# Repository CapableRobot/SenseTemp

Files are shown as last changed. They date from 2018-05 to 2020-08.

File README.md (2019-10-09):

# SenseTemp

Designed by [Capable Robot Components](http://capablerobot.com).  
Follow us on [Twitter](http://twitter.com/capablerobot) for product announcements and updates.

---

**SenseTemp is available on [CrowdSupply](https://www.crowdsupply.com/capable-robot-components/sensetemp) & [Mouser](https://www.mouser.com/Search/Refine?Keyword=sensetemp).  Please visit the [campaign page](https://www.crowdsupply.com/capable-robot-components/sensetemp) or [Mouser](https://www.mouser.com/ProductDetail/Crowd-Supply/cs-sensetemp-01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) for product information and to purchase SenseTemp.** 

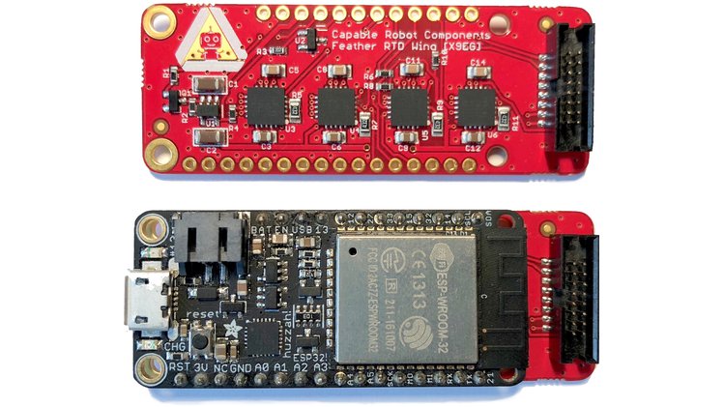
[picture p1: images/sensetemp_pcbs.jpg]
SenseTemp PCB Image


SenseTemp provides four highly accurate and flexible temperature sensors which allow you to understand the operation of your:

* Mobile robot
* Embedded system 
* Double pane windows on your house
* Home brewing operation
* Or any other system where temperature and thermal conduction is important

It's designed for quick tests as well as long-duration process monitoring.

## SenseTemp Features 

* **Small:** so that it can be on a mobile system being tested.  The RTDs themselves are 2 mm x 4 mm, making them thermally responsive and great for measurement of point heat sources
* **Inexpensive:** allowing many points of temperature monitoring
* **Battery Powered:** including LiPoly & USB power banks
* **Wireless:** to make test setup faster and more flexible
* **Open Software:** so that the device can directly feed data into a data logging system of your choice
* **Open Hardware:** to enable derivative designs and for easy hacking

## Specifications

|Feature|Specification|
|----|----|
|Sensors|4x Platinum resistance temperature detectors (RTDs)|
|RTD Accuracy|±0.15°C|
|Temperature Range|-50°C to 260°C|
|Interface ICs|4x [MAX31865](https://www.maximintegrated.com/en/products/sensors/MAX31865.html) with 4 wire sensing|
|Form Factor|[Adafruit Feather](https://www.adafruit.com/feather)|
|Dimensions|0.9" x 2.4"|

## Feather Hosts

SenseTemp is designed to mate with Adafruit Feather-compatible host modules, like:

* [Adafruit Feather M4 Express](https://www.adafruit.com/product/3857)
* [Adafruit Feather M0 Express](https://www.adafruit.com/product/3403)
* [Adafruit ESP32 Feather Host](https://www.adafruit.com/product/3405)
* [Adafruit HalloWing](https://www.adafruit.com/product/3900)

Note that the ES8266 Feather is **NOT** supported due to the limited IO on the ESP8266.  It does not have enough pins to support the four SPI devices of the SenseTemp.

## Software

The software running on the Feather host processor does change based on the feather host you are using.  This repository contains software for:

* [**CircuitPython:**](software-circuitpython) if you are using a Cortex M4 or M0 Feather.  
* [**MicroPython:**](software-micropython) if you are using an ESP32 Feather.  The ESP32 is not currently supported by CircuitPython.

## Hardware Revisions

* [CREAES](revisions/CREAES) : Last release 2018-10-18.
	* Changed from 0805 to 0603 passive components.
	* Moved all components to top side of PCB.
	* Changed license from **CC BY-SA 4.0** to **CERN OHL v1.2**.
	* Can be powered from either USB or Li-Ion sources.
* [X9EG](revisions/X9EG) : Released 2018-08-28.
	* Added `SIO` pin with AT21CS01 1-Wire EEPROM for configuration & serialization.
	* Added `EN` pin to allow host PCB to disable 5v to 3v regulator on this PCB.
	* Changed RTD connector from 20 pin (used on XTMT version) to 16 pin.
* [XTMT](revisions/XTMT) : Initial version released 2018-05-18.

## License Information

| **Type** | **License** |
| --- | --- |
| Hardware | Copyright Capable Robot Components 2018 <br><br>This documentation describes Open Hardware and is licensed under the [CERN OHL v1.2 or later](https://www.ohwr.org/licenses/cern-ohl/license_versions/v1.2). <br/><br/> You may redistribute and modify this documentation under the terms of the CERN OHL v.1.2.  This documentation is distributed WITHOUT ANY EXPRESS OR IMPLIED WARRANTY, INCLUDING OF MERCHANTABILITY, SATISFACTORY QUALITY AND FITNESS FOR A PARTICULAR PURPOSE. Please see the CERN OHL v.1.2 for applicable conditions |
| Software | [MIT License](LICENSE.txt) |
| Documentation | [Creative Commons Attribution-ShareAlike](https://creativecommons.org/licenses/by-sa/4.0/) License |

More detailed information about the CERN License is available in the [license](license) folder and on the [CERN website](https://www.ohwr.org/projects/cernohl/wiki).

| **OSHW Certification** |
| --- |
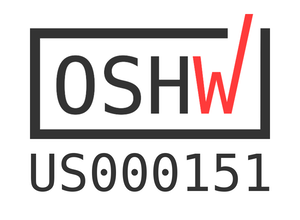
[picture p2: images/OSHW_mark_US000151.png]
OSHW Mark US000151
|  | 
| [Certified open source hardware](https://certification.oshwa.org/us000151.html) by the [Open Source Hardware Association](https://www.oshwa.org) |

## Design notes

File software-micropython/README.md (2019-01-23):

# MicroPython SenseTemp

Designed by [Capable Robot Components](http://capablerobot.com).  Follow us on [Twitter](http://twitter.com/capablerobot) for product announcements and updates.

---

This folder contains MicroPython software for use of the SenseTemp with the [Adafruit ESP32 Feather Host](https://www.adafruit.com/product/3405).

## System Setup

1. Install tools

```
pip3 install esptool adafruit-ampy
```

2. Flash MicroPython onto the device

```
espefuse.py --port /dev/ttyUSB1 set_flash_voltage 3.3V
esptool.py --port /dev/ttyUSB1 --chip esp32 erase_flash
esptool.py --port /dev/ttyUSB1 --chip esp32  write_flash -z 0x1000 ../firmware/esp32-20180511-v1.9.4.bin
```

The first command is necessary if the SenseTemp PCB has been soldered to the ESP32 module, due to the PCB pulling up GPIO12 (the SIO pin).

On MacOS, the port name will likely be `/dev/tty.SLAB_USBtoUART`.

By default, the ESP32 sees that as a signal to provide the flash chip with 1.8v instead of the default 3.3v.  This causes the SPI flash to brown out during writing and the MD5 checksum verify step will fail (because the flash is corrupted).  Setting the EFUSE causes the ESP32 to ignore the GPIO12 pin and always provide 3.3v to the SPI flash.

3. Load MicroPython source files (see below)

### Console Demo

```
ampy put lib
ampy put main-console.py main.py
```

### MQTT Demo

After creating the JSON file, you'll need to edit it to have your correct WIFI and Adafruit.io information.

```
cp settings-mqtt.json.example settings-mqtt.json 
ampy put lib
ampy put settings-mqtt.json 
ampy put main-mqtt.py main.py
```

### WIFI Demo

After creating the JSON file, you'll need to edit it to have your correct WIFI information.  Due the size of the `www` folder, this will take a few minutes.  Be patient.  

```
cp settings.json.example settings.json 
ampy put lib
ampy put www
ampy put settings.json
ampy put main.py
```

## Development

During development, it's best to load the main file under a different name so that the firmware does not automatically execute it.  

If the MicroPython code hangs, the ampy tool has a hard time putting the ESP32 module into raw communication mode (wherein it can upload files).  These commands can be used to 

1. Upload the in-development main.py file
2. Open a serial console (you will need to change the path) to the MicroPython REPL.
3. Start the in-development software.  Errors will be printed to the REPL.

```
ampy put main.py tmp.py
screen /dev/ttyUSB1 115200
> from tmp import *
```

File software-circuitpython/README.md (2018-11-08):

# SenseTemp with CircuitPython

Designed by [Capable Robot Components](http://capablerobot.com).  
Follow us on [Twitter](http://twitter.com/capablerobot) for product announcements and updates.

---

**SenseTemp is currently in-pre launch on CrowdSupply.  You can sign up on the [campaign page](https://www.crowdsupply.com/capable-robot-components/sensetemp) for project update.** 

---

During the [2018 Hackaday Supercon](https://hackaday.io/superconference/), Adafruit donated HalloWing badges to the attendees and I wrote the CiruitPython code released here, which graphs temperatures from SenseTemp on the HalloWing LCD.  

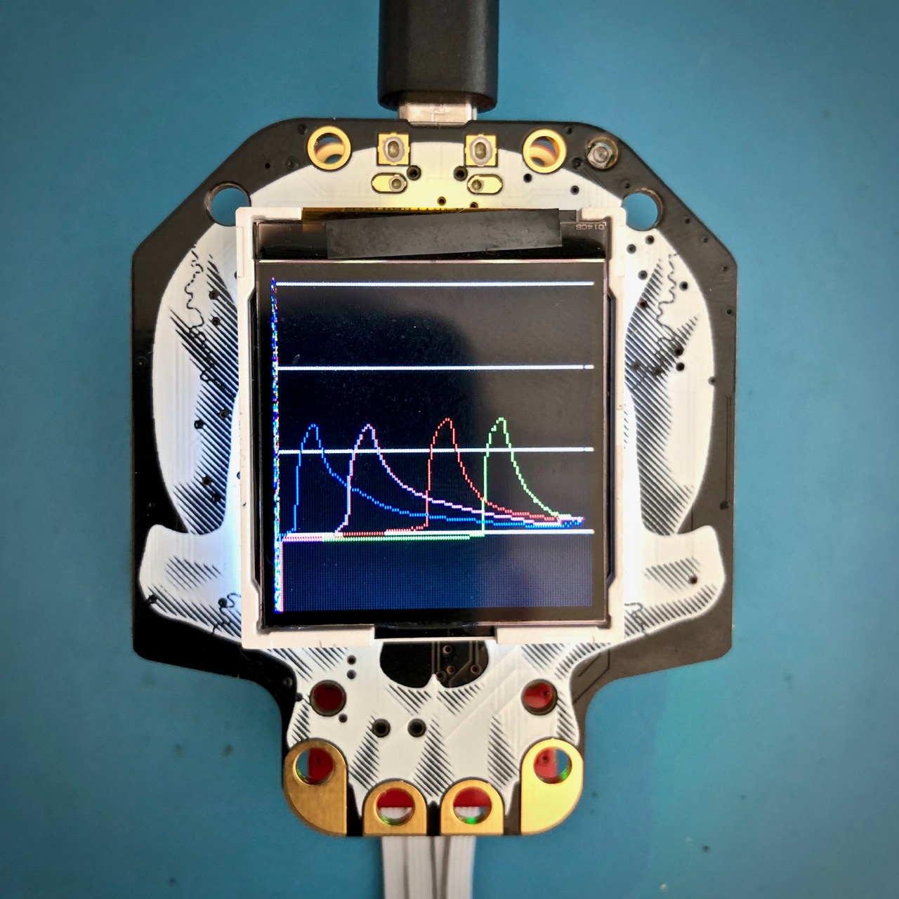
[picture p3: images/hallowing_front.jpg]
Hallowing displaying temperature data from SenseTemp
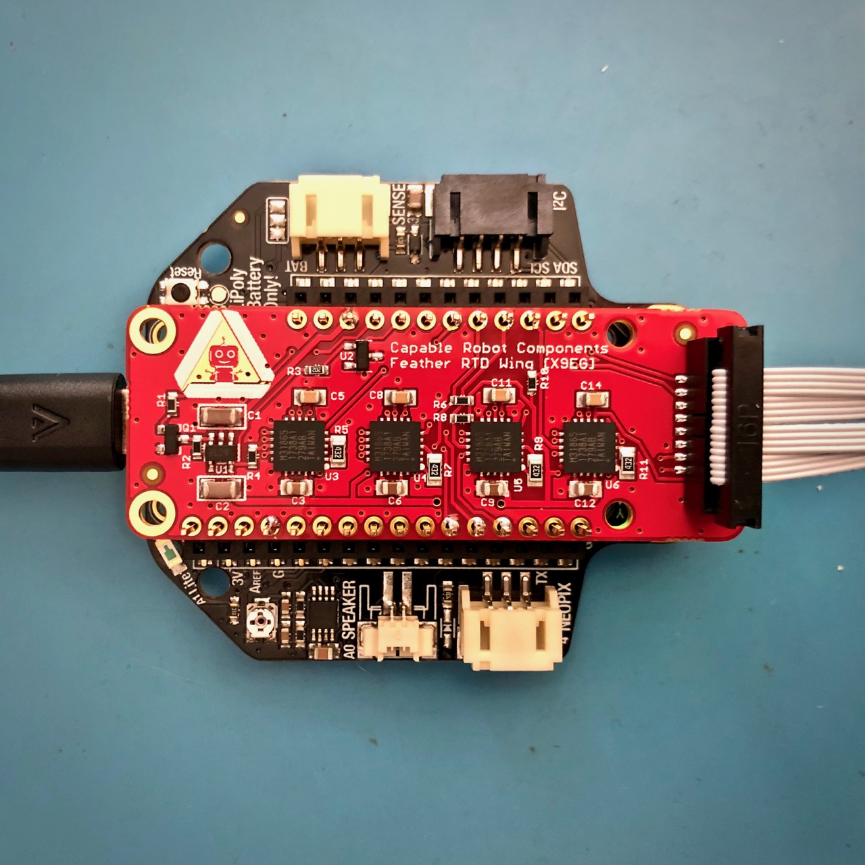
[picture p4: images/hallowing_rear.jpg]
SenseTemp installed into HalloWing Feather socket
|||
|:---:|:---:|
|HalloWing showing a time-history graph of the four temperature sensors.  Vertical scale is 60F to 100F.| Rear of HallowWing, showing SenseTemp board installed|

The full code is in `code-hallowing.py`, which should be renamed `code.py` so that it is auto-run by CircuitPython.

The main part of the display routine is shown here:

```python
## Determine vertical position for the temperature sample
def f_to_px(value):
    if value < TEMP_MIN:
        return 0

    if value > TEMP_MAX:
        return DISPLAY_PX-1

    px = (value - TEMP_MIN) * DISPLAY_PX / (TEMP_MAX - TEMP_MIN)
    return int(px)

## Re-draw the grid data at this position
def draw_grid_at_position(position):
    ## Clear all samples at this X position.
    display.vline(position, 0, DISPLAY_PX, color565(0,0,0))

    ## Draw white grid lines at this X position
    ## to re-create the temperature scale
    for value in temp_grid:
        y = f_to_px(value)
        display.pixel(position, y, color565(255,255,255))

## Stores the last PX position for each temperature value
## this allows code to determine if new sample should be
## drawing with a point, or a line
last_px = [0,0,0,0]

def draw_temps_graph(position, data):
    draw_grid_at_position(position)

    for idx,value in enumerate(data):
        y     = f_to_px(c_to_f(value))
        dy    = abs(y - last_px[idx])
        color = color565(*COLORMAP[idx])

        if dy > 1:
            ypos = min(y, last_px[idx])
            display.vline(position, ypos, dy, color)
        else:
            display.pixel(position, y, color)

        last_px[idx] = y

## Draw horizontal lines as a temperature scale
for value in temp_grid:
    y = f_to_px(value)
    display.hline(0, y, DISPLAY_PX, color565(255,255,255))

## Start on the left side of the screen
position = DISPLAY_PX

## Advance to the next PX position, read temperature data, draw it
while True:
    position -= 1

    data = [sensor.temperature for sensor in sensors]
    draw_temps_graph(position, data)

    ## We're at the end of the display, go back to the left side
    if position <= 0:
        position = DISPLAY_PX
```

Nearly any Feather Host running CircuitPython will support SenseTemp.  The only exception known to date is the ESP8266 Host as it does not have enough IO pins for the 4 SPI chip select pins.

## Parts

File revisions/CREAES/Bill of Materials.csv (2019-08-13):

Name | Mpn | Count | Device | Value | Package | Mfg | Cost | Description
C15,C16 | CL21A106KPFNNNE | 2 | CAP-0805 | 10u | 0805 | Samsung | 0.1088
C3,C4,C6,C7,C9,C10,C12,C13 | MF-CAP-0603-0.1uF | 8 | CAP-0603 | 100n | 0603 | Generic
C5,C8,C11,C14 | MF-CAP-0603-0.01uF | 4 | CAP-0603 | 10n | 0603 | Generic
D1 | MBR120VLSFT3G | 1 | DIODE-SCHOTTKY-SOD-123 | MBR120 | SOD-123 | ON Semiconductor | 0.16
FB1,FB2,FB3,FB4 | BK1608HW601-T | 4 | FER-0603 | 600R | 0603 | Taiyo Yuden | 0.11350000000000002
Q1 | MMBT2222LT1G | 1 | TRANSISTOR_NPN-SOT23-3 | MMBT2222 | SOT23-3 | ON Semiconductor | 0.0642
Q2 | DMP2045U-7 | 1 | MOSFET-P | DMP2045 | SOT23-R | Diodes Inc. | 0.124
R1,R2,R3 | MF-RES-0603-1K | 3 | RES-0603 | 1k | 0603 | Generic
R12 | MF-RES-0603-100K | 1 | RES-0603 | 100k | 0603 | Generic
R4,R6,R8,R10,R16 | MF-RES-0603-10K | 5 | RES-0603 | 10k | 0603 | Generic
R5,R7,R9,R11 | ERA3ARW432V | 4 | RES-0603 | 4k3 0.05% | 0603 | Panasonic | 1.7916
RTD1 | 3221-16-0300-00 | 1 | CONN-16-ZT |  | CONN-2X8-050-SMT-ZT | CNC Tech | 0.946
U2 | AT21CS01-STUM10-T | 1 | AT21CS01 |  | SOT23 | Microchip | 0.1836
U3,U4,U5,U6 | MAX31865ATP+ | 4 | MAX31865 |  | QFN65P500X500X100-21T325 | Maxim Integrated | 12.336
U7 | AP2112K-3.3TRG1 | 1 | MIC5225 | 3v3 | SOT25 | Diodes Inc. | 0.15

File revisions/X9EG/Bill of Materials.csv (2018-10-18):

Name | Count | Device | Value | Package | Description
C1,C2 | 2 | CAP_CERAMIC-_1206 | 10uF | _1206
C3,C4,C6,C7,C9,C10,C12,C13 | 8 | CAP_CERAMIC-0805-NOOUTLINE | 0.1uF | 0805-NO
C5,C8,C11,C14 | 4 | CAP_CERAMIC-0805-NOOUTLINE | 10nF | 0805-NO
FB1,FB2,FB3,FB4 | 4 | FERRITE--0805NO |  | 0805-NO
J1 | 1 | CONN_12-NO_SILK |  | 1X12_NO_SILK
J2 | 1 | CONN_16-1X16_NO_SILK |  | 1X16_NO_SILK
Q1 | 1 | TRANS_NPN--MMBT2222AL | 600mA/40V | SOT23-3
R1 | 1 | RES-0603 | 1k | 0603
R2,R4,R6,R8,R10 | 5 | RES-0603 | 10k | 0603
R3 | 1 | RES-0603 | 2k | 0603
R5,R7,R9,R11 | 4 | RESISTOR-0805_NOOUTLINE | 4300Ω 0.1% | 0805-NO
RTD1 | 1 | CONN-16-ZT |  | CONN-2X8-050-SMT-ZT
U1 | 1 | VREG_SOT23-5 | MIC5225-3.3 | SOT23-5
U2 | 1 | AT21CS01 |  | SOT23
U3,U4,U5,U6 | 4 | TEMP_MAX31865 | MAX31865 | QFN20_4MM_0.65MM

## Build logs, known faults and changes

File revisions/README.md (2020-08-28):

# SenseTemp Hardware Revisions

Designed by [Capable Robot Components](http://capablerobot.com).  
Follow us on [Twitter](http://twitter.com/capablerobot) for product announcements and updates.

---

**SenseTemp is available on [CrowdSupply](https://www.crowdsupply.com/capable-robot-components/sensetemp) & [Mouser](https://www.mouser.com/Search/Refine?Keyword=sensetemp).  Please visit the [campaign page](https://www.crowdsupply.com/capable-robot-components/sensetemp) or [Mouser](https://www.mouser.com/ProductDetail/Crowd-Supply/cs-sensetemp-01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) for product information and to purchase SenseTemp.** 

SenseTemp PCB Image

---

* [CREAES](revisions/CREAES) : Last release 2018-10-18.
	* Changed from 0805 to 0603 passive components.
	* Moved all components to top side of PCB.
	* Changed license from **CC BY-SA 4.0** to **CERN OHL v1.2**.
	* Can be powered from either USB or Li-Ion sources.
* [X9EG](revisions/X9EG) : Released 2018-08-28.
	* Added `SIO` pin with AT21CS01 1-Wire EEPROM for configuration & serialization.
	* Added `EN` pin to allow host PCB to disable 5v to 3v regulator on this PCB.
	* Changed RTD connector from 20 pin (used on XTMT version) to 16 pin.
* [XTMT](revisions/XTMT) : Initial version released 2018-05-18.

---

Also in this folder are two adapter PCBs which allows SenseTemp's 50mil (4x 4-wire) connector to be adapted to 4x 2-way 5mm screw terminals, allowing SenseTemp to use 2-wire and 3-wire (in 2-wire mode) P1000 RTDs.

The 'stacking' design has the same outline and mounting as SenseTemp and is designed to stack vertically above SenseTemp using a [AMP Minitek 20021321-00016C4LF](https://octopart.com/20021321-00016c4lf-amphenol+icc+%2F+fci-12642443?r=sp) (or similar) connector.

The 'cabled' design is smaller and cabled to SenseTemp via a 16 conductor, 50 mil ribbon cabled.  The recommended 16 pin connector for it is [CNC Tech 3221-16-0300-00](https://octopart.com/3221-16-0300-00-cnc+tech-47114357?r=sp) or similar.

Bare PCBs (e.g. no components installed or included) are available for purchase directly from OSHPark:

| [Cabled Adapter](https://oshpark.com/shared_projects/WjlpBAlQ) | [Stacking Adapter](https://oshpark.com/shared_projects/11pGTiwa) |
|---|---|
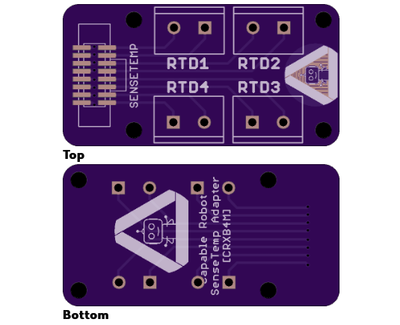
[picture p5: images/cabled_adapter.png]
Cabled Adapter Image (https://oshpark.com/shared_projects/WjlpBAlQ)
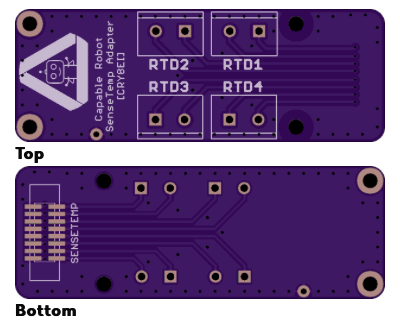
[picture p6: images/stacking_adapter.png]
Stacking Adapter Image (https://oshpark.com/shared_projects/11pGTiwa)
||  |

---

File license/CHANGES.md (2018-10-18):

Here we are compiling a community changelog.

If you come up with a modification of our designs, please share it
with the community, log your changes below, and upload the files to
our GitHub repository.

# Change Format

**NAME** on DATE by *Your name*.
Description of modification

# Change Log

* **[CREAES](https://github.com/CapableRobot/SenseTemp/tree/master/revisions/CREAES)** on 2018-10-18 by *Chris Osterwood*
	* Changed from 0805 to 0603 passive components.
	* Moved all components to top side of PCB.
	* Added `USR` pin for user-controllable LED near the RTD connector.
	* Changed license from **CC BY-SA 4.0** to **CERN OHL v1.2**.
* **[X9EG](https://github.com/CapableRobot/SenseTemp/tree/master/revisions/X9EG)** on 2018-08-28 by *Chris Osterwood*
	* Added `SIO` pin with AT21CS01 1-Wire EEPROM for configuration & serialization.
	* Added `EN` pin to allow host PCB to disable 5v to 3v regulator on this PCB.
	* Changed RTD connector from 20 pin (used on XTMT version) to 16 pin.
* **[XTMT](https://github.com/CapableRobot/SenseTemp/tree/master/revisions/XTMT)** 2018-05-18 by *Chris Osterwood*

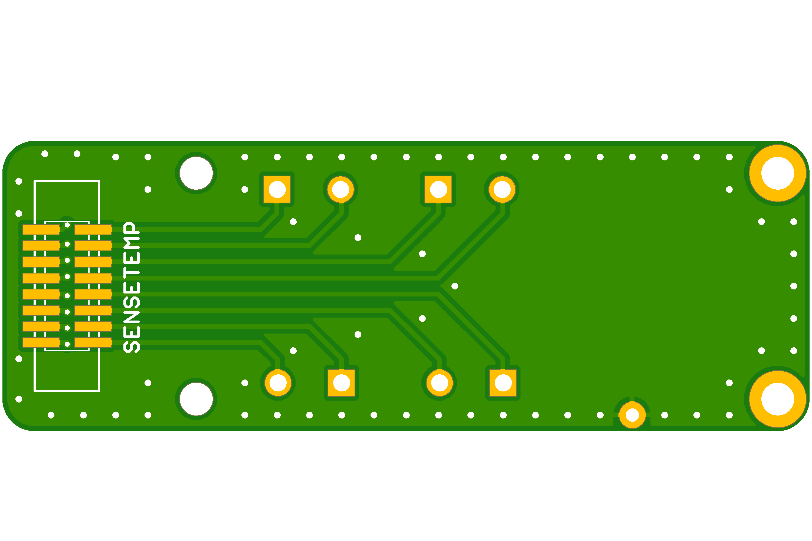
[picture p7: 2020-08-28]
revisions/Adapter - Stacking 2 wire/bottom.png

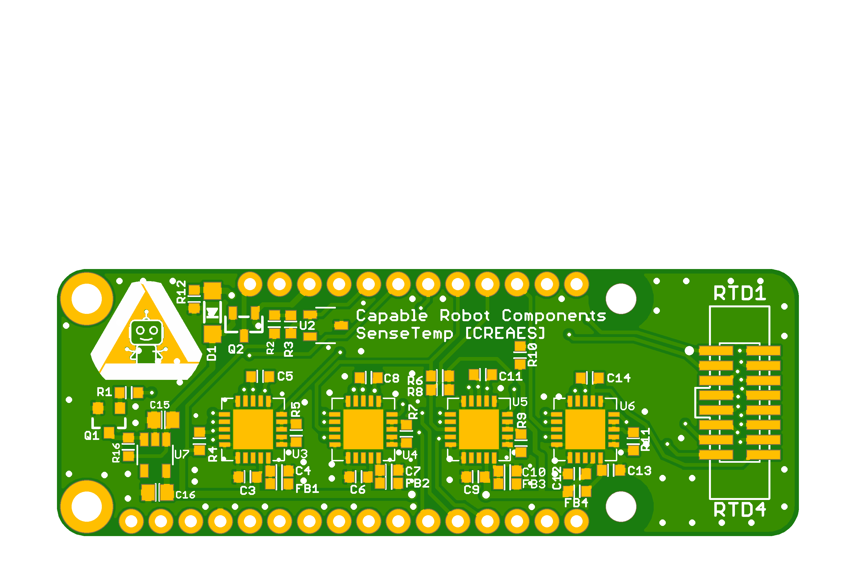
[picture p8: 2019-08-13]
revisions/CREAES/SenseTemp - CREAES - top.png

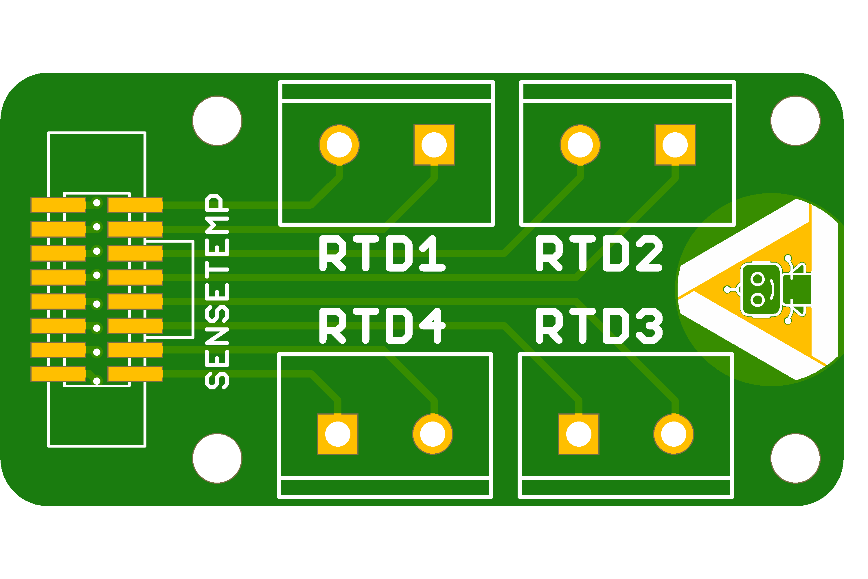
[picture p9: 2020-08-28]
revisions/Adapter - Cabled 2 wire/top.png

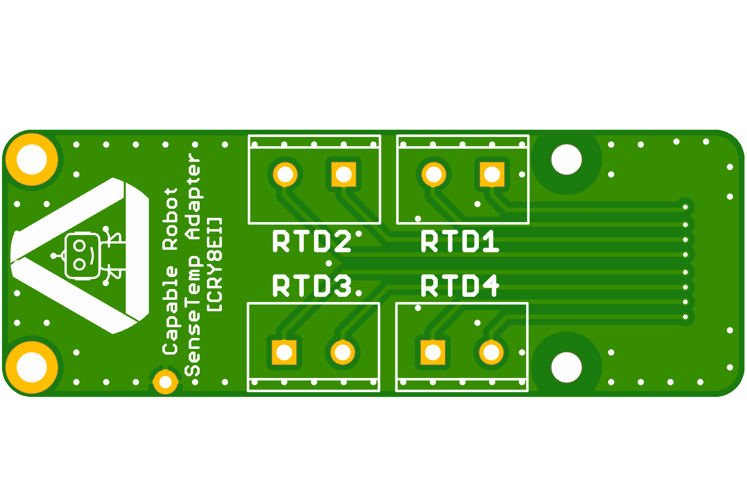
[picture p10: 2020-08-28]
revisions/Adapter - Stacking 2 wire/top.png

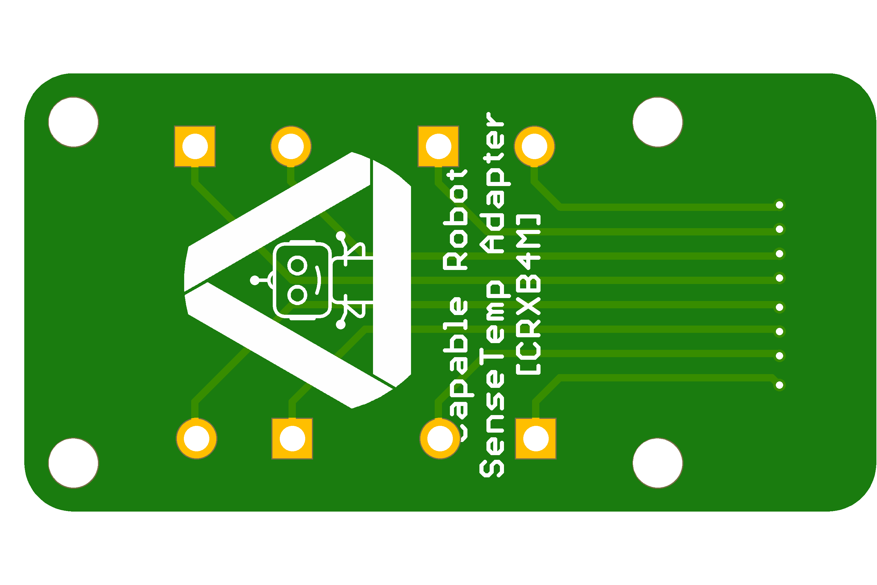
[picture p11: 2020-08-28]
revisions/Adapter - Cabled 2 wire/bottom.png

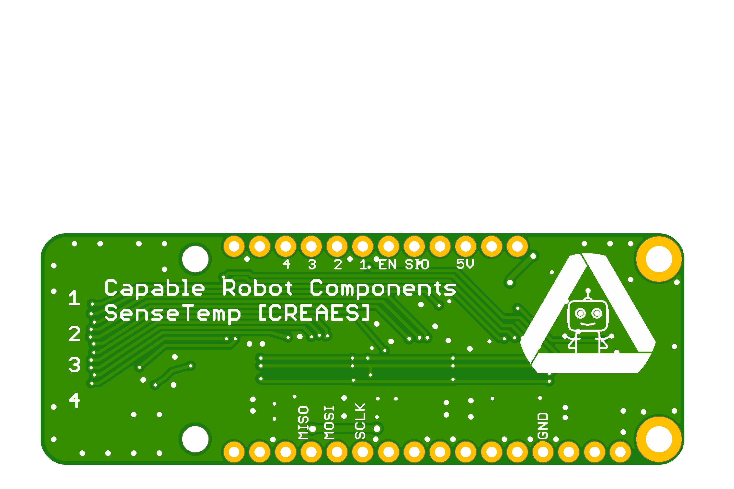
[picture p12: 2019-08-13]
revisions/CREAES/SenseTemp - CREAES - bottom.png

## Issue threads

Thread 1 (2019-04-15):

Support for 3 wire RTDs

osterwood, 2019-04-15:
It may be advantageous for some applications to support 3 wire RTDs.  This requires connecting pin 6 (FORCE2) of the MAX31865 to Pin 5 (FORCE+) instead of to GND.  Right now there is do way to make this change due to boards' layout and the Pin 6 GND connecting existing underneath the IC.

The layout could be changed in the future to add a solder jumper allowing pin 6's connection to be selected by the end user.

osterwood, 2020-08-28:
As an interim step, two adapter boards have been designed which allow connection of 2 wire RTD (or 3-wire in 2 wire mode) via 5mm screw terminals.

It looks like the error introduced by this is not too bad (0.13C at 100C) and with a 3-wire RTD leg resistance and be accurately measured and error compensation done in software inside of the MCU.

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

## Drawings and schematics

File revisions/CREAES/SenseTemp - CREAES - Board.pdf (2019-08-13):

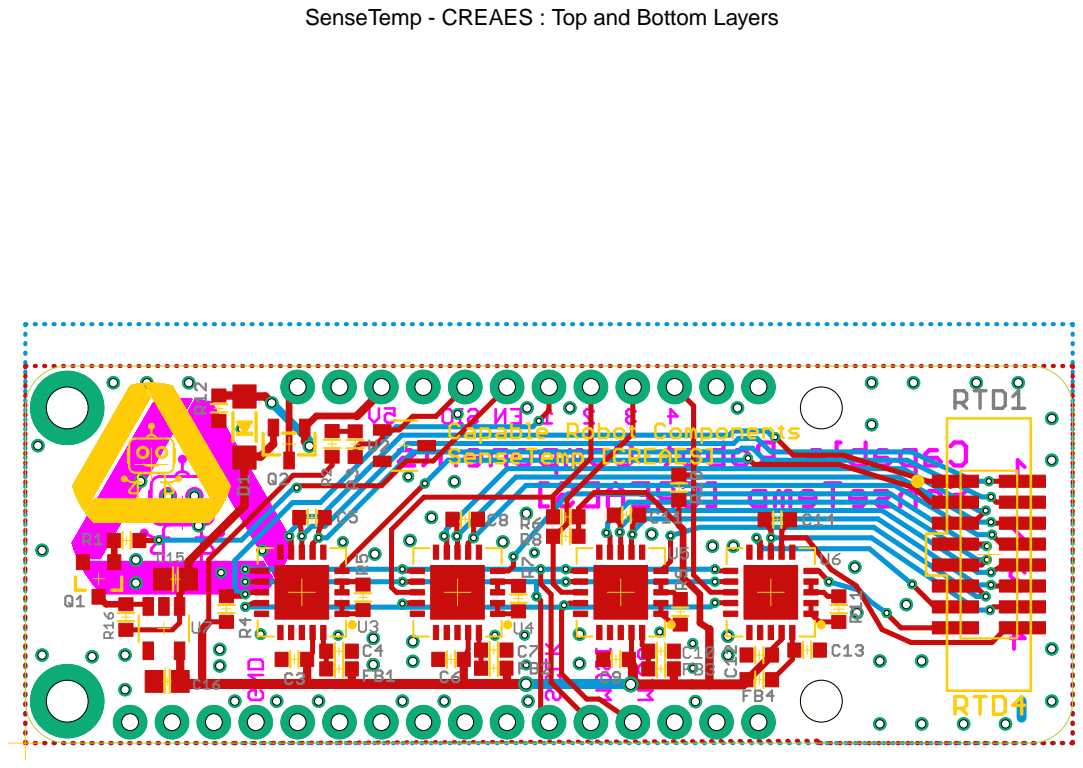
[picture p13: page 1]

SenseTemp - CREAES : Top and Bottom Layers

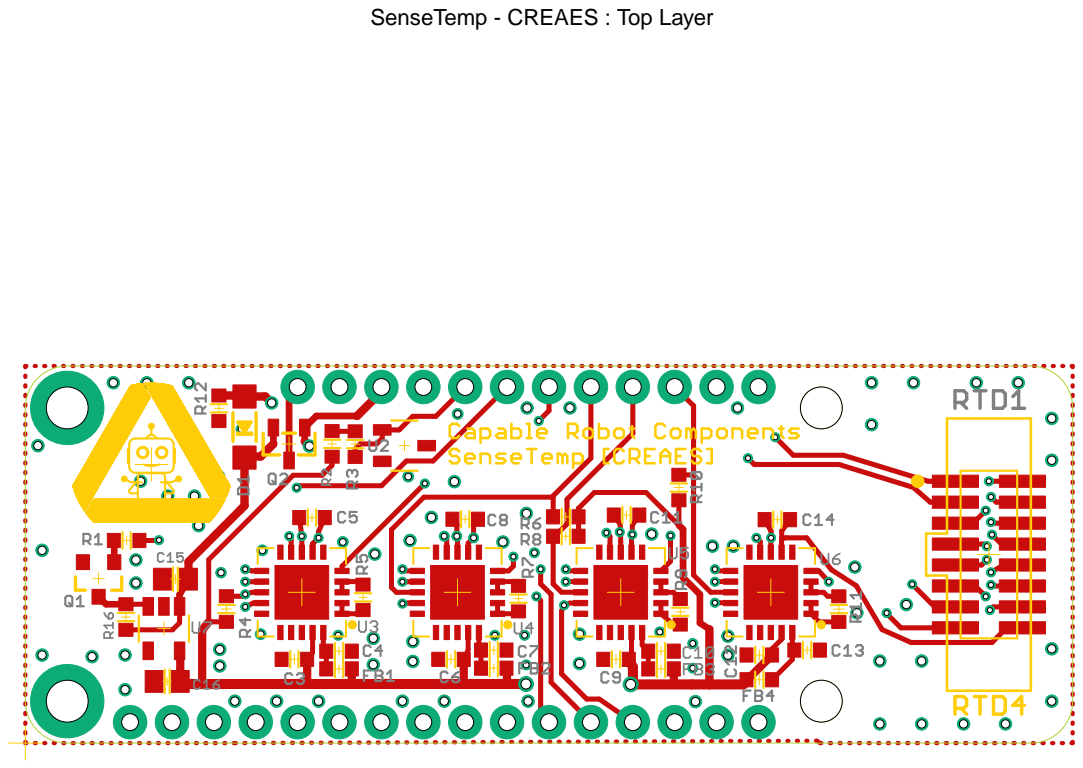
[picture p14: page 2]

SenseTemp - CREAES : Top Layer

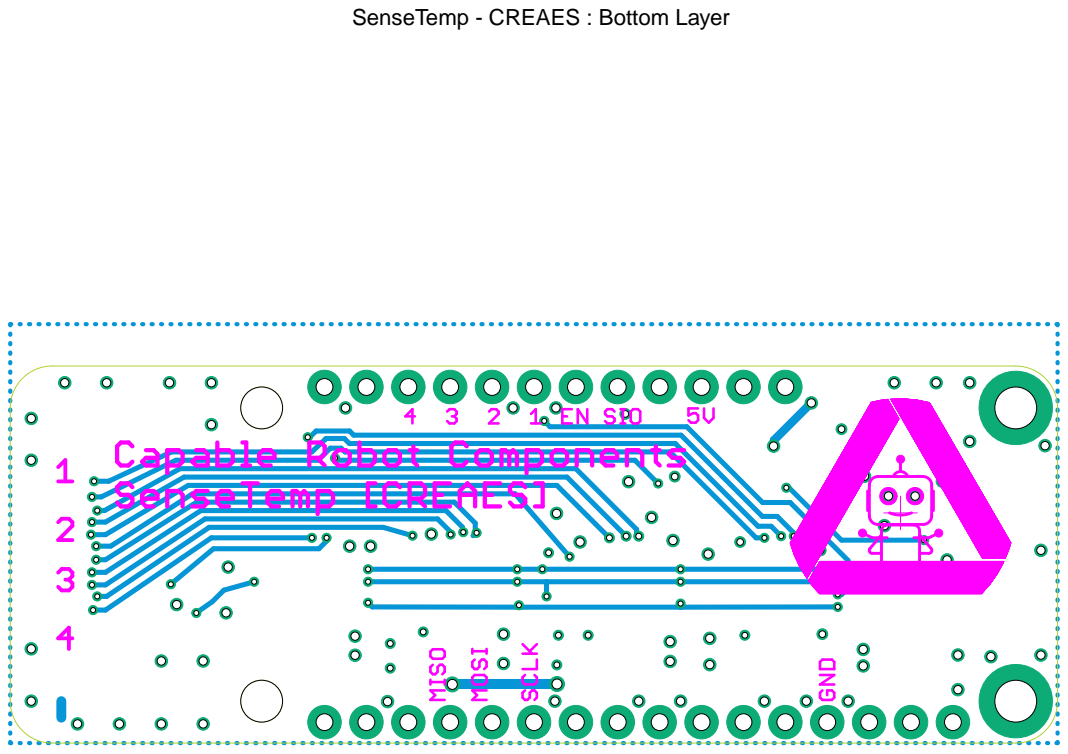
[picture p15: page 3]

SenseTemp - CREAES : Bottom Layer

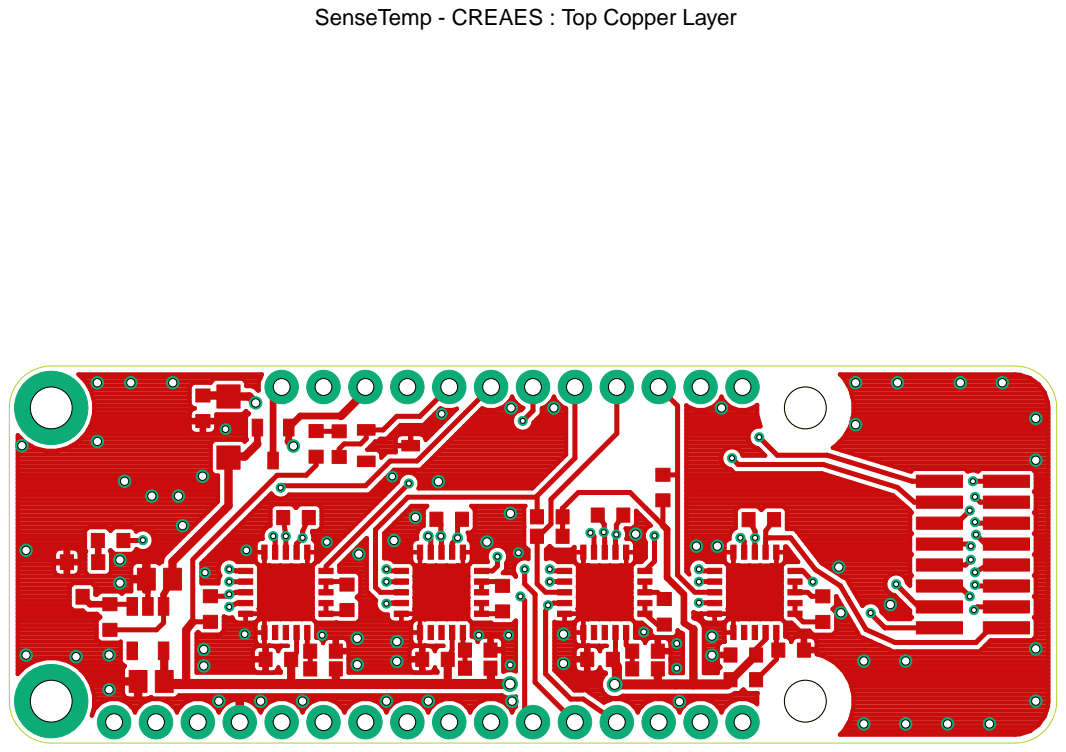
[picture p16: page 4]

SenseTemp - CREAES : Top Copper Layer

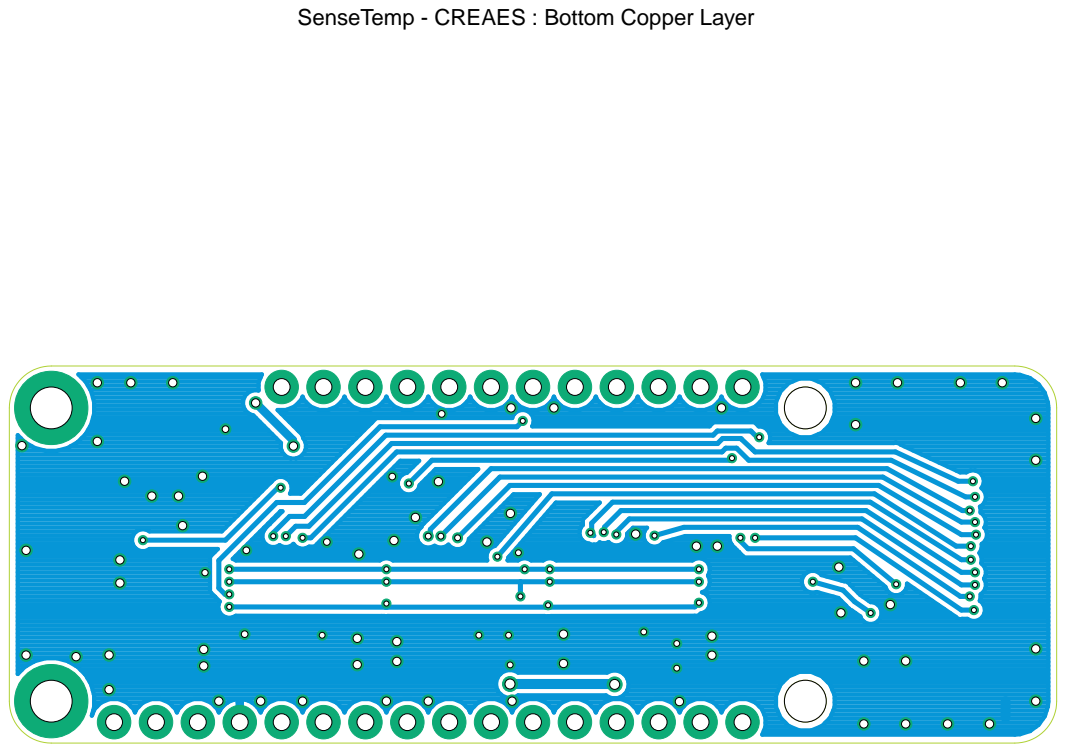
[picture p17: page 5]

SenseTemp - CREAES : Bottom Copper Layer

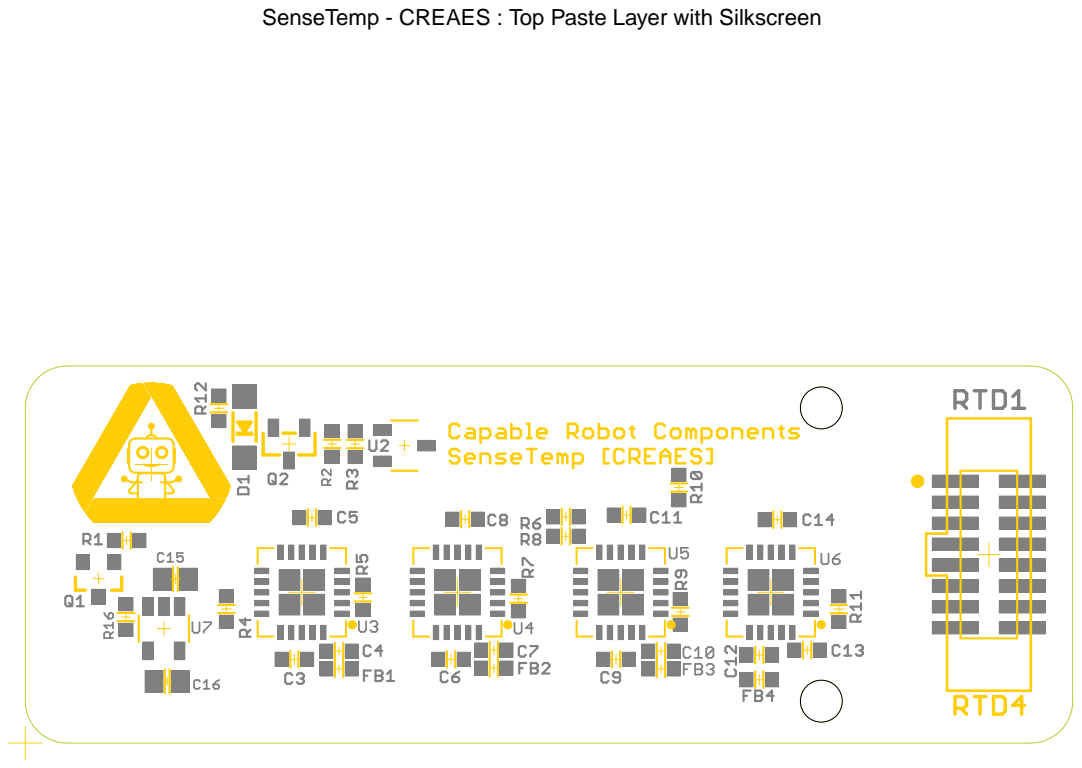
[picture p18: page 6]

SenseTemp - CREAES : Top Paste Layer with Silkscreen

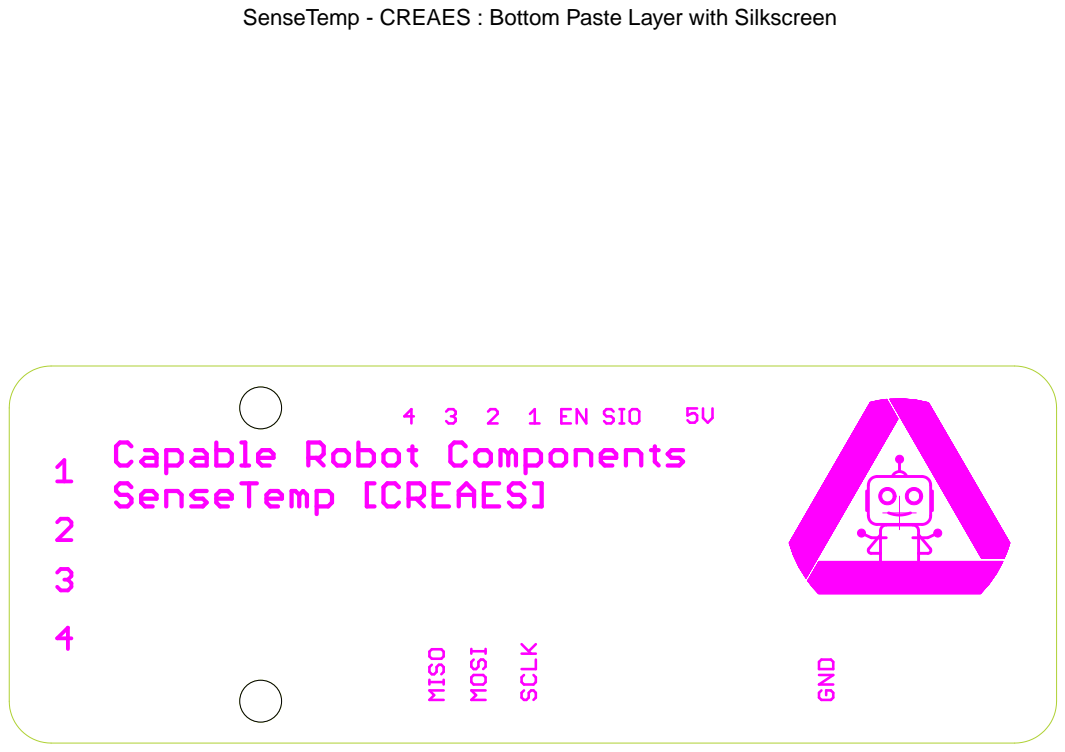
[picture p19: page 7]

SenseTemp - CREAES : Bottom Paste Layer with Silkscreen

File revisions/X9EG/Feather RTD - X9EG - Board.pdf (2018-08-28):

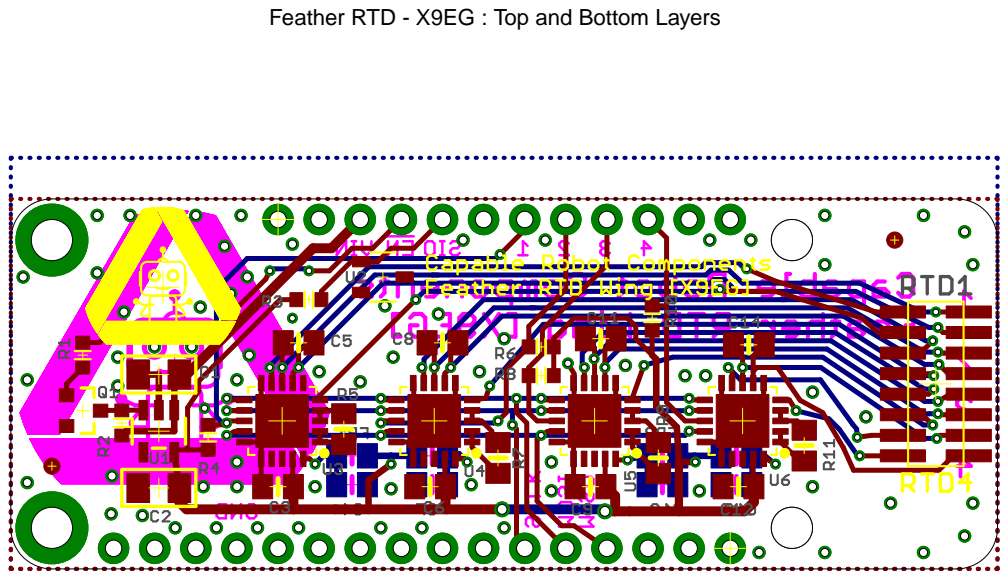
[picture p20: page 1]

Feather RTD - X9EG : Top and Bottom Layers

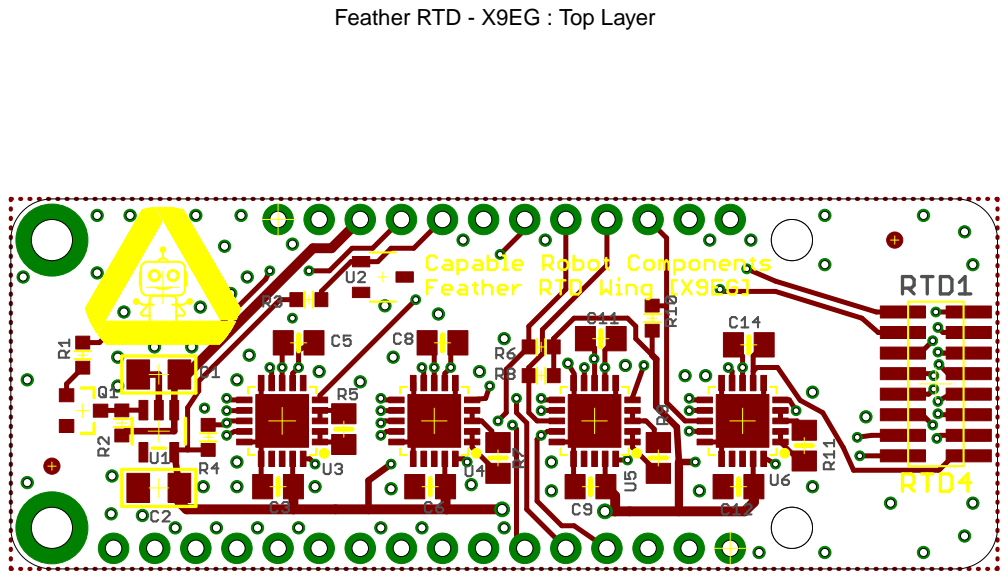
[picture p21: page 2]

Feather RTD - X9EG : Top Layer

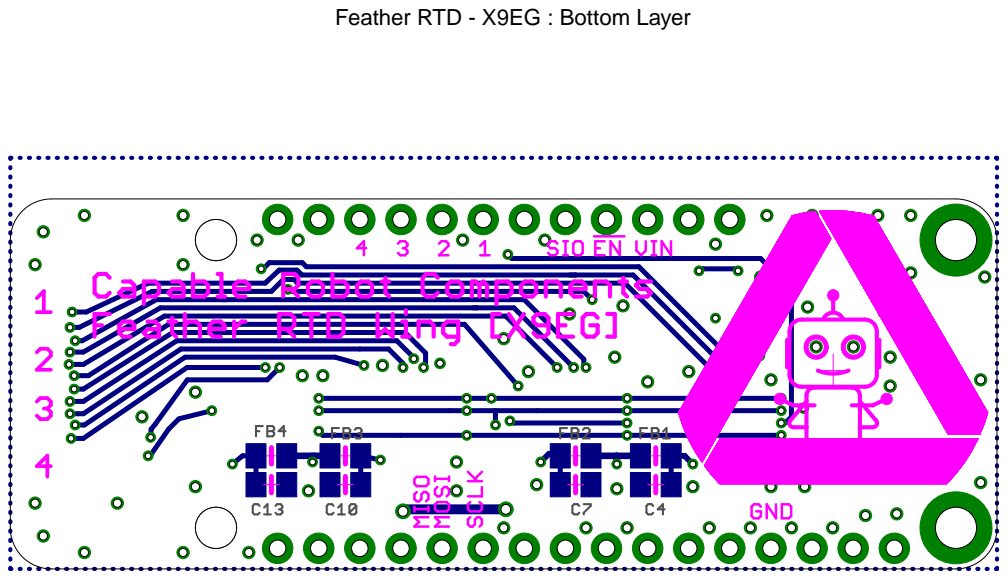
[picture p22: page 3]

Feather RTD - X9EG : Bottom Layer

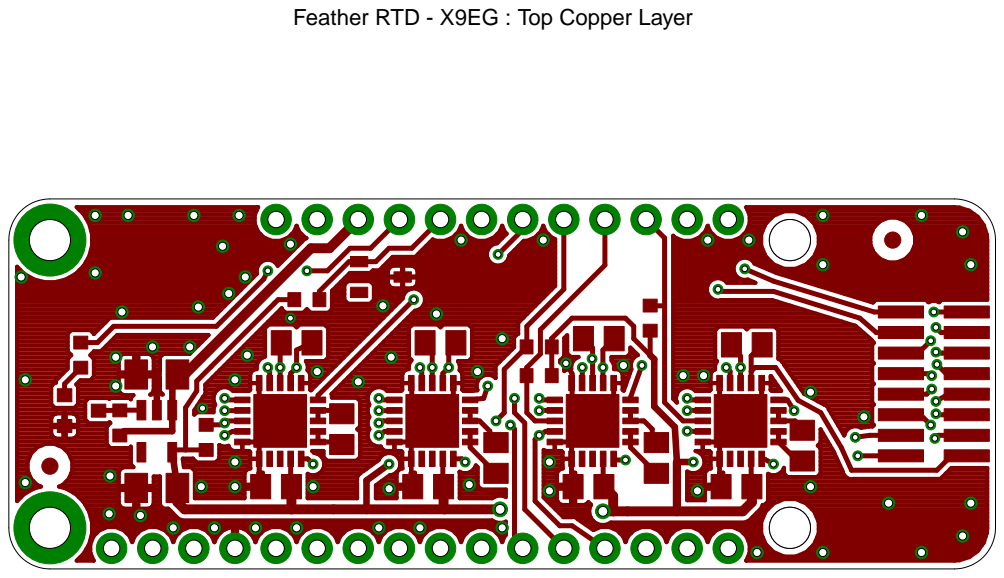
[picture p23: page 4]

Feather RTD - X9EG : Top Copper Layer

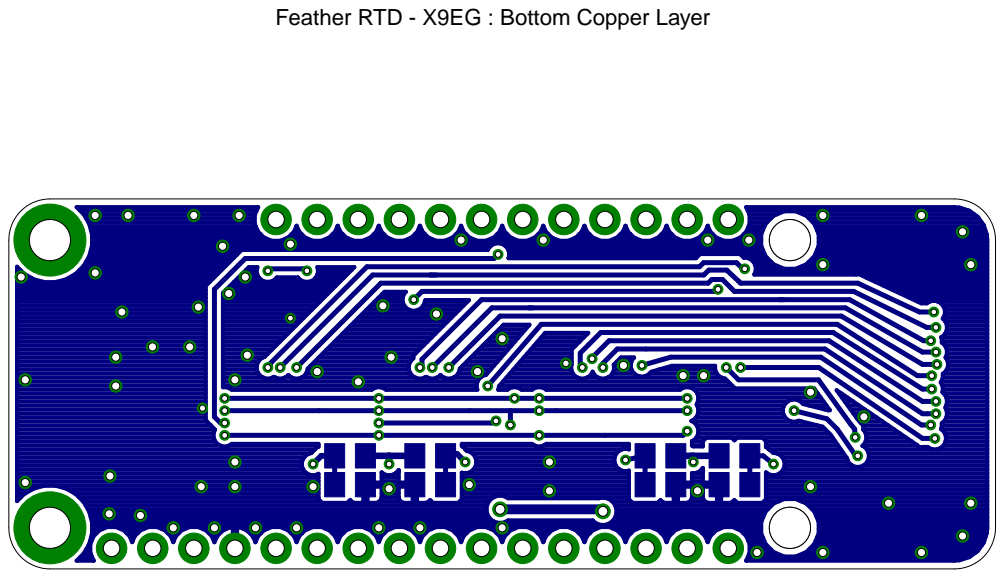
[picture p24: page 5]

Feather RTD - X9EG : Bottom Copper Layer


Feather RTD - X9EG : Top Paste Layer with Silkscreen


Feather RTD - X9EG : Bottom Paste Layer with Silkscreen

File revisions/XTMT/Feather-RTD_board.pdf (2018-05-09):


Feather-RTD : Top and Bottom Layers


Feather-RTD : Top Layer


Feather-RTD : Bottom Layer


Feather-RTD : Top Copper Layer


Feather-RTD : Bottom Copper Layer


Feather-RTD : Top Paste Layer with Silkscreen


Feather-RTD : Bottom Paste Layer with Silkscreen

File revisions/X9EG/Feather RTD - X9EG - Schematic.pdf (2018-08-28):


URL
https://github.com/CapableRobot/Feather-RTD


4x RTD resistance at 0°C
Use high quality 1% or better resistors


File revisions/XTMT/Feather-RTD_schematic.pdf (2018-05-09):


URL
https://github.com/CapableRobot/Feather-RTD


4x RTD resistance at 0°C
Use high quality 1% or better resistors


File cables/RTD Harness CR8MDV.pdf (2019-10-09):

RTD; Pin 1; Pin 16; Heraeus; RTD Sensor, L420 Series; 14mm long; See #2 below; Notes; 1.2mm dial heat shrink; Description; Cicoil; CNC Tech; QTY; MFG; MPN

Overall Length AA (cm) +/- 5mm

Closeup of IDC
Connector

Closeup of a RTD Sensor

IDC Connector, 16 Conductor

Ribbon Cable, 4 Conductor

Cut to AA cm +/- 5mm

White Heat Shrink

Notes:
Solder each pair to 1 leg of RTD at point 8mm from base of RTD & clean off flux.
Slide heat shrink up over solder joint. Shrink by applying heat.

Install 4x 4C ribbon cables into 16C connector. Crimp. Install retaining clip.
Install white heat shrink (C) with channel number over each strip, 4” from end.
Split end of each strip into 2 pairs of 2 conductors for last 25mm.
Install TE heat shrink (E) over each pair of wires.
Strip last 3mm of each wire pair.

Capable Robot Components

Product SenseTemp | Revision CREASE

Drawing Harness-AA | Revision CR8MDV

“AA” in part number specifies overall length of cable in cm.
Approximately 5mm of cable is folded over and inside of IDC connector and
RTD length is 5mm, so cut length of cable matches overall assembly length.

2019-01-18 Date | 1/1 Sheet




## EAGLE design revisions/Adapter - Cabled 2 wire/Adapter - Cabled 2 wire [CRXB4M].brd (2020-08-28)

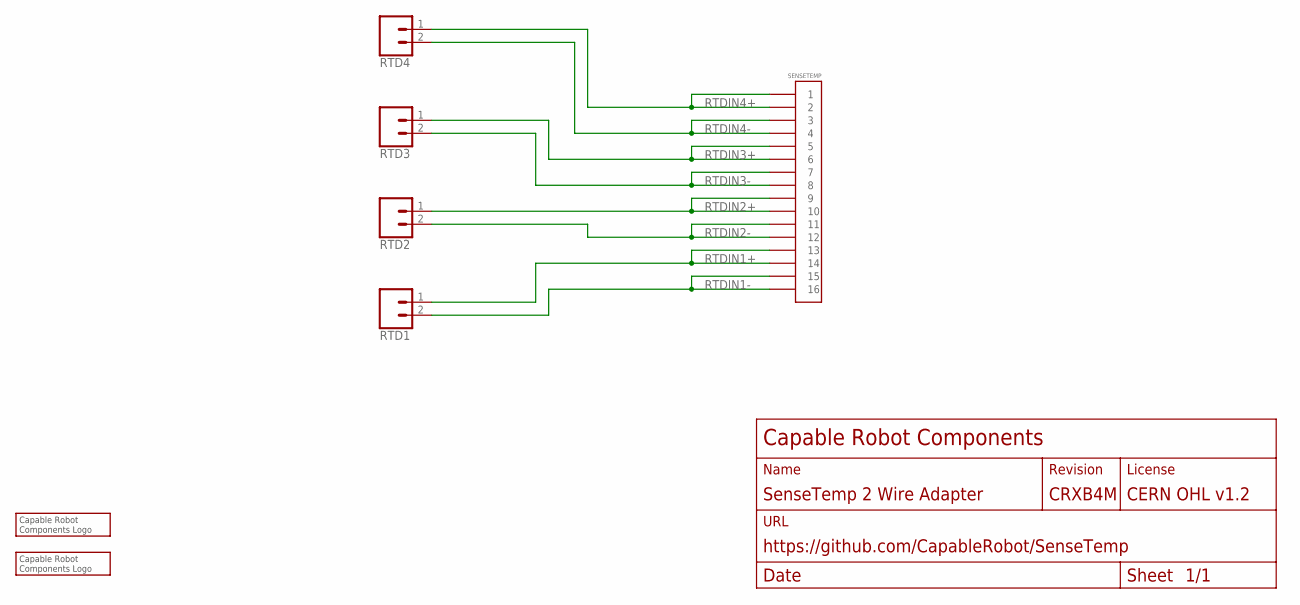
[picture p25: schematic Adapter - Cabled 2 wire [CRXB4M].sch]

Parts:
LOGO1: CRC-LOGO7SILK; CRC-LOGO-7-SILK
LOGO2: CRC-LOGO5; CRC-LOGO-5
RTD1, RTD2, RTD3, RTD4: CONN_025MM; SCREWTERMINAL-5MM-2
SENSETEMP: CONN-16ZT; CONN-2X8-050-SMT-ZT; MPN 3221-16-0300-00

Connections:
RTDIN1+: RTD1.1, SENSETEMP.13, SENSETEMP.14
RTDIN1-: RTD1.2, SENSETEMP.15, SENSETEMP.16
RTDIN2+: RTD2.1, SENSETEMP.9, SENSETEMP.10
RTDIN2-: RTD2.2, SENSETEMP.11, SENSETEMP.12
RTDIN3+: RTD3.1, SENSETEMP.5, SENSETEMP.6
RTDIN3-: RTD3.2, SENSETEMP.7, SENSETEMP.8
RTDIN4+: RTD4.1, SENSETEMP.1, SENSETEMP.2
RTDIN4-: RTD4.2, SENSETEMP.3, SENSETEMP.4

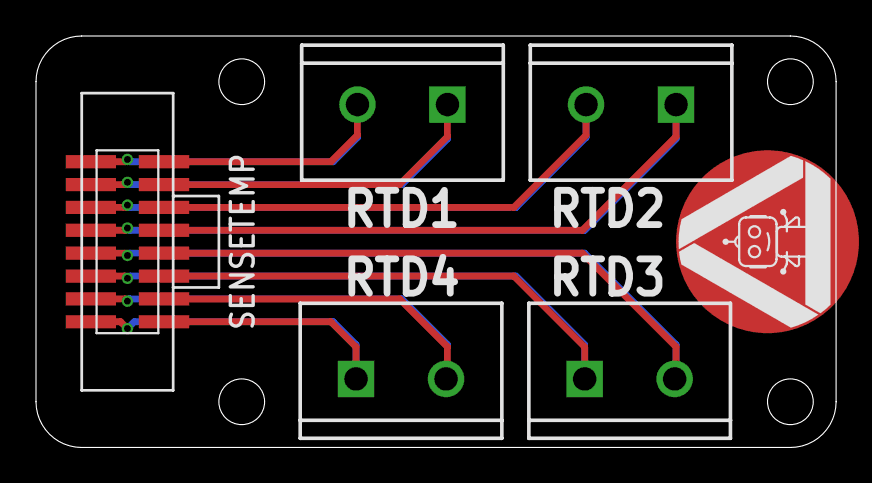
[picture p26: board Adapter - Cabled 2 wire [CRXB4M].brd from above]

Board: 2 copper layers, 44.5 x 22.9 mm, 7 parts (1 on the bottom side), 8 nets.

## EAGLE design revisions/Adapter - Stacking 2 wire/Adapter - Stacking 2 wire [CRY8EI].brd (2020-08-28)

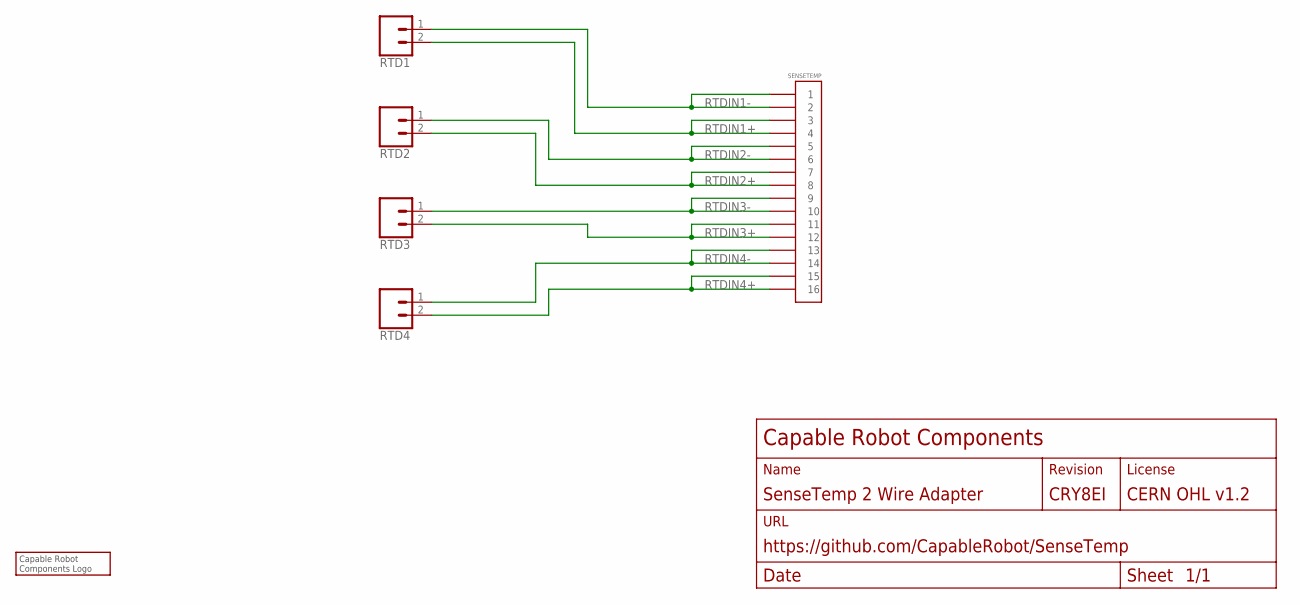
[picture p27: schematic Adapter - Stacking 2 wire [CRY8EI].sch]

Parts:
LOGO1: CRC-LOGO7SILK; CRC-LOGO-7-SILK
RTD1, RTD2, RTD3, RTD4: CONN_025MM; SCREWTERMINAL-5MM-2
SENSETEMP: CONN-16ZT; CONN-2X8-050-SMT-ZT; MPN 3221-16-0300-00

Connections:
RTDIN1+: RTD1.2, SENSETEMP.3, SENSETEMP.4
RTDIN1-: RTD1.1, SENSETEMP.1, SENSETEMP.2
RTDIN2+: RTD2.2, SENSETEMP.7, SENSETEMP.8
RTDIN2-: RTD2.1, SENSETEMP.5, SENSETEMP.6
RTDIN3+: RTD3.2, SENSETEMP.11, SENSETEMP.12
RTDIN3-: RTD3.1, SENSETEMP.9, SENSETEMP.10
RTDIN4+: RTD4.2, SENSETEMP.15, SENSETEMP.16
RTDIN4-: RTD4.1, SENSETEMP.13, SENSETEMP.14

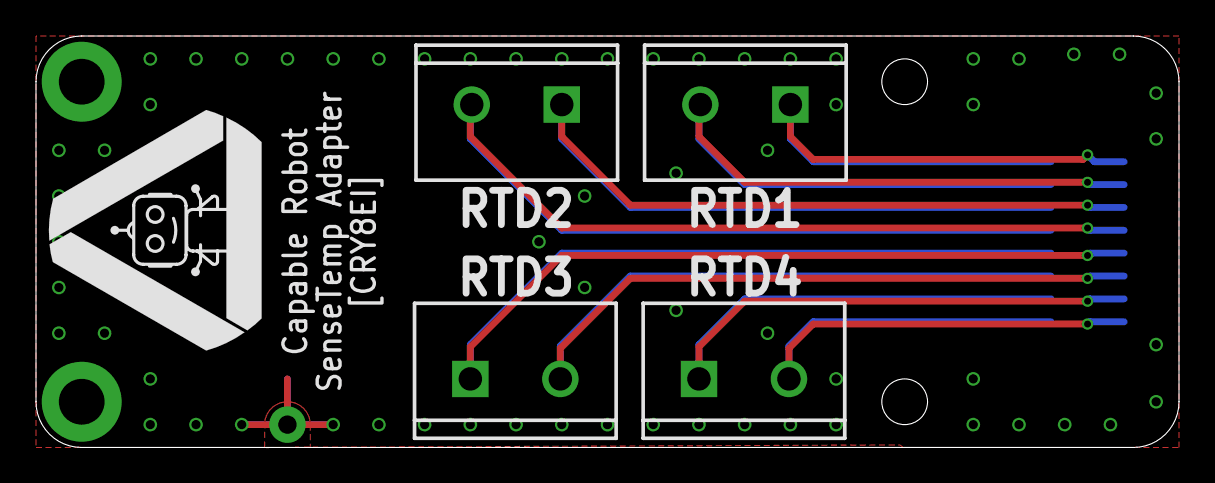
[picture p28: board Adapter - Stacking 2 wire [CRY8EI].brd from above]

Board: 2 copper layers, 63.5 x 22.9 mm, 6 parts (1 on the bottom side), 8 nets.

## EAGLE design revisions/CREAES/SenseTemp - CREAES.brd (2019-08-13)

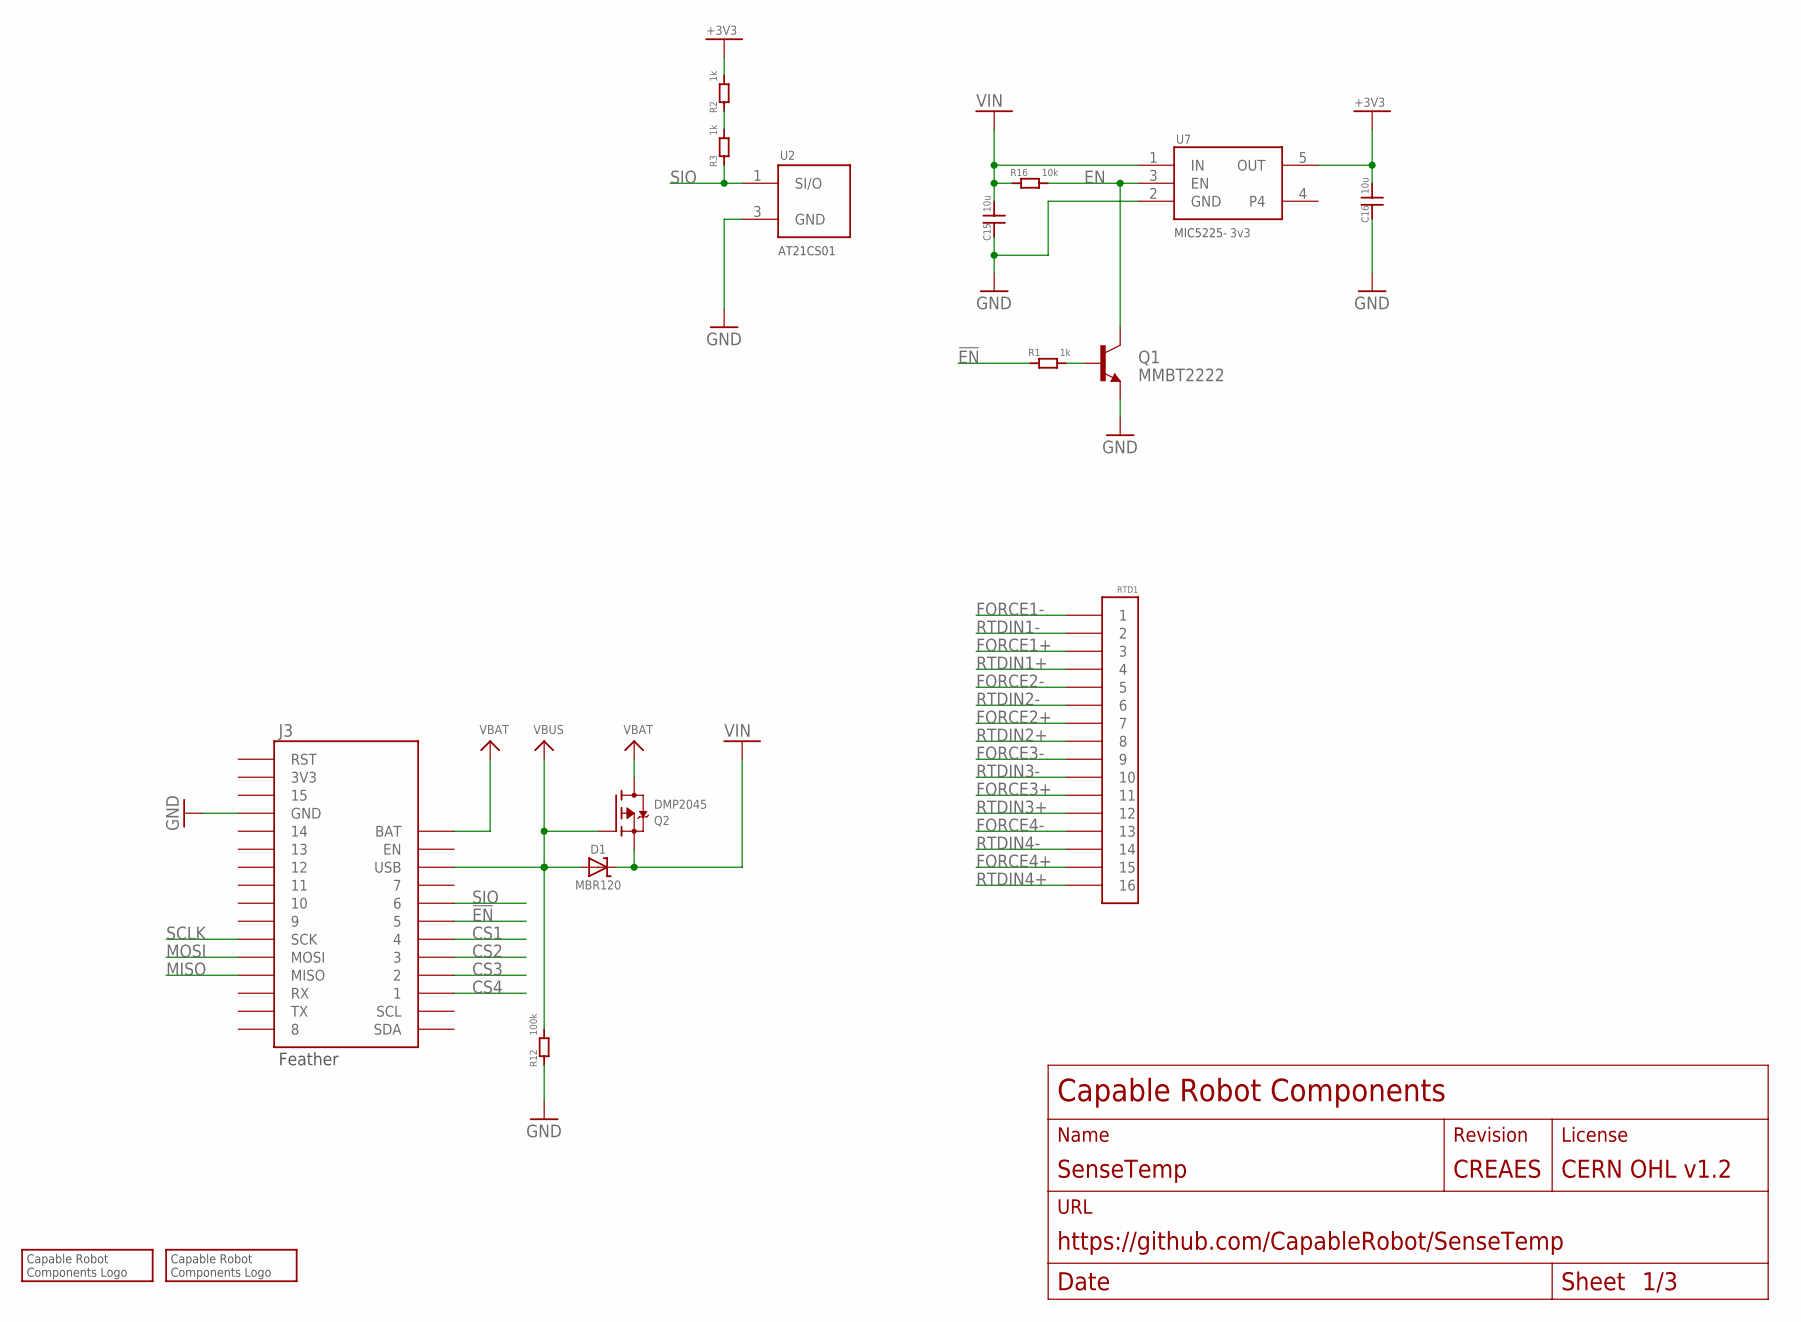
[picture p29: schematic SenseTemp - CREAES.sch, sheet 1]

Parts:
C15, C16: 10u; 0805
D1: MBR120; SOD-123; MPN MBR120VLSFT3G
J3: FEATHERPTH; FEATHER-PTH
LOGO1: CRC-LOGO7SILK; CRC-LOGO-7-SILK
LOGO2: CRC-LOGO5; CRC-LOGO-5
Q1: MMBT2222; SOT23-3; MPN MMBT2222LT1G
Q2: DMP2045; SOT23-R; MPN DMP2045U-7
R1, R2, R3: 1k; 0603
R12: 100k; 0603
R16: 10k; 0603
RTD1: CONN-16ZT; CONN-2X8-050-SMT-ZT; MPN 3221-16-0300-00
U2: AT21CS01; SOT23
U7: 3v3; SOT25

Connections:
!EN: J3.5, R1.1
+3V3: C16.2, R2.2, U7.5 (OUT); also elsewhere on the board
CS1: J3.4; also elsewhere on the board
CS2: J3.3; also elsewhere on the board
CS3: J3.2; also elsewhere on the board
CS4: J3.1; also elsewhere on the board
EN: Q1.3 (C), R16.2, U7.3 (EN)
FORCE1+: RTD1.3; also elsewhere on the board
FORCE1-: RTD1.1; also elsewhere on the board
FORCE2+: RTD1.7; also elsewhere on the board
FORCE2-: RTD1.5; also elsewhere on the board
FORCE3+: RTD1.11; also elsewhere on the board
FORCE3-: RTD1.9; also elsewhere on the board
FORCE4+: RTD1.15; also elsewhere on the board
FORCE4-: RTD1.13; also elsewhere on the board
GND: C15.1, C16.1, J3.GND, Q1.2 (E), R12.1, U2.3 (GND), U7.2 (GND); also elsewhere on the board
MISO: J3.MISO; also elsewhere on the board
MOSI: J3.MOSI; also elsewhere on the board
unnamed: R2.1, R3.2
unnamed: Q1.1 (B), R1.2
RTDIN1+: RTD1.4; also elsewhere on the board
RTDIN1-: RTD1.2; also elsewhere on the board
RTDIN2+: RTD1.8; also elsewhere on the board
RTDIN2-: RTD1.6; also elsewhere on the board
RTDIN3+: RTD1.12; also elsewhere on the board
RTDIN3-: RTD1.10; also elsewhere on the board
RTDIN4+: RTD1.16; also elsewhere on the board
RTDIN4-: RTD1.14; also elsewhere on the board
SCLK: J3.SCK; also elsewhere on the board
SIO: J3.6, R3.1, U2.1 (SI/O)
VBAT: J3.BAT, Q2.3 (D)
VBUS: D1.A, J3.USB, Q2.1 (G), R12.2
VIN: C15.2, D1.C, Q2.2 (S), R16.1, U7.1 (IN)

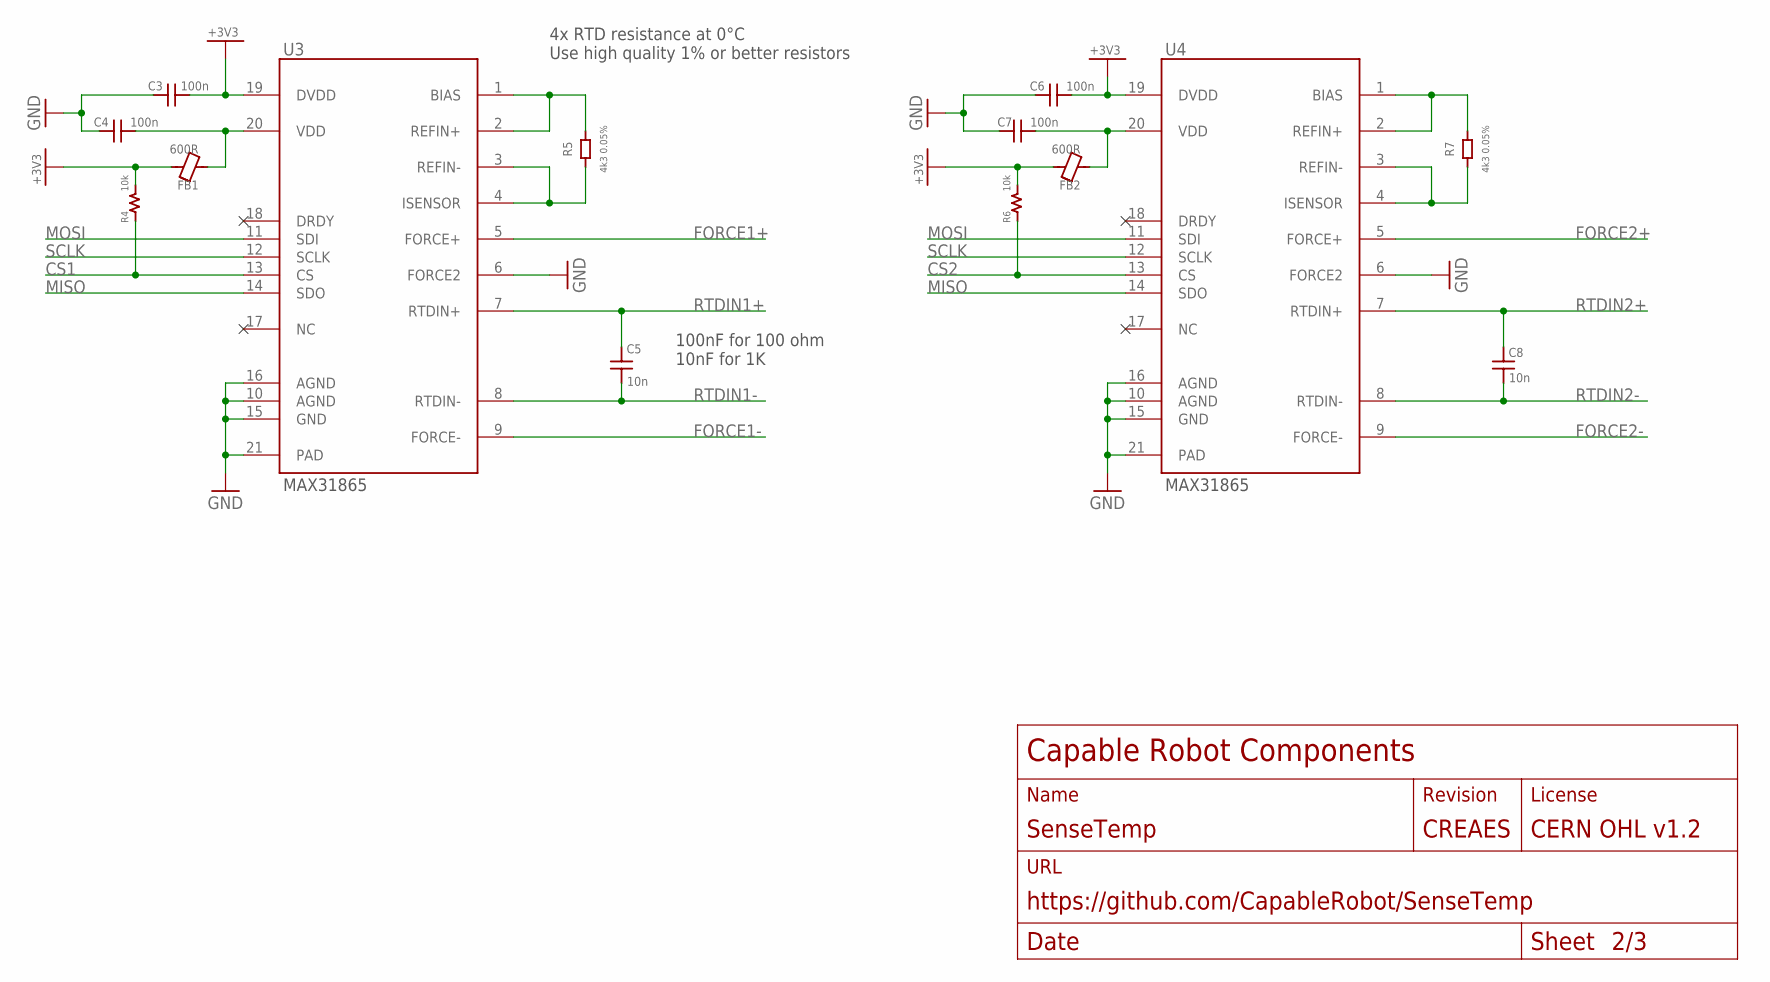
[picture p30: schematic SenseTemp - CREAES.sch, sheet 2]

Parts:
C3, C4, C6, C7: 100n; 0603
C5, C8: 10n; 0603
FB1, FB2: 600R; 0603
R4, R6: 10k; 0603
R5, R7: 4k3 0.05%; 0603
U3, U4: MAX31865; QFN65P500X500X100-21T325

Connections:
+3V3: C3.1, C6.1, FB1.2, FB2.2, R4.2, R6.2, U3.19 (DVDD), U4.19 (DVDD); also elsewhere on the board
CS1: R4.1, U3.13 (CS); also elsewhere on the board
CS2: R6.1, U4.13 (CS); also elsewhere on the board
FORCE1+: U3.5 (FORCE+); also elsewhere on the board
FORCE1-: U3.9 (FORCE-); also elsewhere on the board
FORCE2+: U4.5 (FORCE+); also elsewhere on the board
FORCE2-: U4.9 (FORCE-); also elsewhere on the board
GND: C3.2, C4.2, C6.2, C7.2, U3.6 (FORCE2), U3.10 (AGND), U3.15 (GND), U3.16 (AGND), U3.21 (PAD), U4.6 (FORCE2), U4.10 (AGND), U4.15 (GND), U4.16 (AGND), U4.21 (PAD); also elsewhere on the board
MISO: U3.14 (SDO), U4.14 (SDO); also elsewhere on the board
MOSI: U3.11 (SDI), U4.11 (SDI); also elsewhere on the board
unnamed: R5.2, U3.1 (BIAS), U3.2 (REFIN+)
unnamed: R5.1, U3.3 (REFIN-), U3.4 (ISENSOR)
unnamed: C4.1, FB1.1, U3.20 (VDD)
unnamed: R7.2, U4.1 (BIAS), U4.2 (REFIN+)
unnamed: R7.1, U4.3 (REFIN-), U4.4 (ISENSOR)
unnamed: C7.1, FB2.1, U4.20 (VDD)
RTDIN1+: C5.1, U3.7 (RTDIN+); also elsewhere on the board
RTDIN1-: C5.2, U3.8 (RTDIN-); also elsewhere on the board
RTDIN2+: C8.1, U4.7 (RTDIN+); also elsewhere on the board
RTDIN2-: C8.2, U4.8 (RTDIN-); also elsewhere on the board
SCLK: U3.12 (SCLK), U4.12 (SCLK); also elsewhere on the board

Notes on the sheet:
4x RTD resistance at 0°C Use high quality 1% or better resistors
100nF for 100 ohm 10nF for 1K

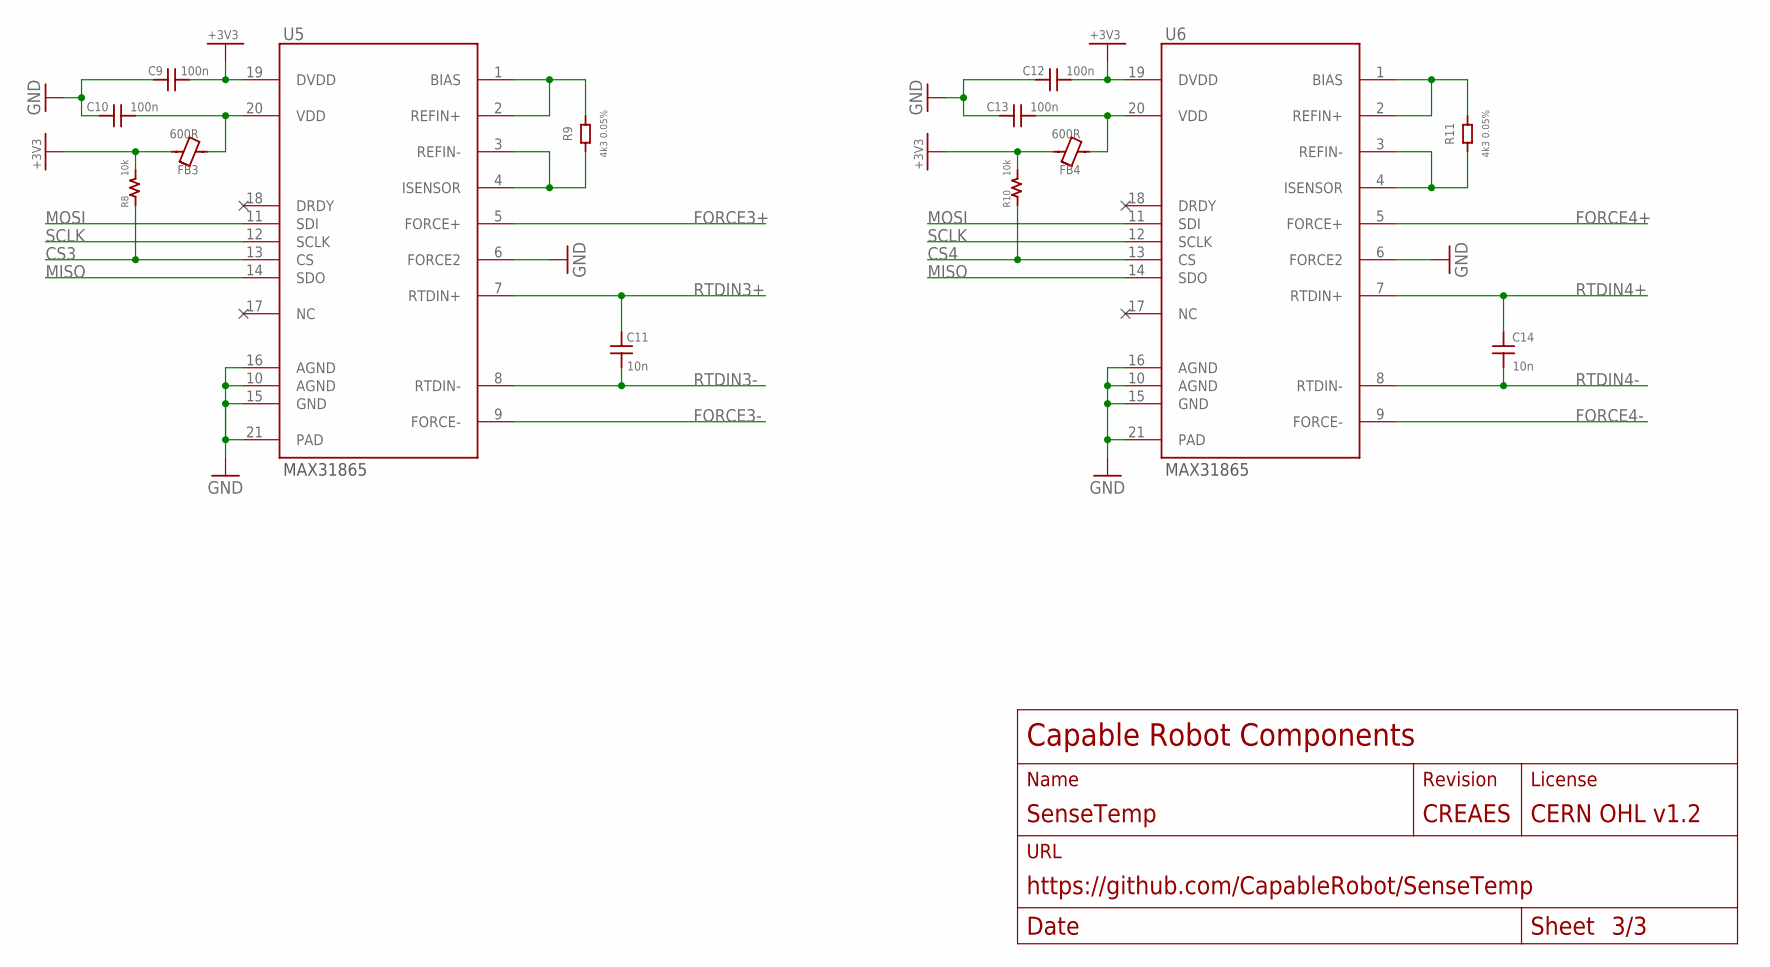
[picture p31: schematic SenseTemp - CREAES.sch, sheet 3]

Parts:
C9, C10, C12, C13: 100n; 0603
C11, C14: 10n; 0603
FB3, FB4: 600R; 0603
R8, R10: 10k; 0603
R9, R11: 4k3 0.05%; 0603
U5, U6: MAX31865; QFN65P500X500X100-21T325

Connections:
+3V3: C9.1, C12.1, FB3.2, FB4.2, R8.2, R10.2, U5.19 (DVDD), U6.19 (DVDD); also elsewhere on the board
CS3: R8.1, U5.13 (CS); also elsewhere on the board
CS4: R10.1, U6.13 (CS); also elsewhere on the board
FORCE3+: U5.5 (FORCE+); also elsewhere on the board
FORCE3-: U5.9 (FORCE-); also elsewhere on the board
FORCE4+: U6.5 (FORCE+); also elsewhere on the board
FORCE4-: U6.9 (FORCE-); also elsewhere on the board
GND: C9.2, C10.2, C12.2, C13.2, U5.6 (FORCE2), U5.10 (AGND), U5.15 (GND), U5.16 (AGND), U5.21 (PAD), U6.6 (FORCE2), U6.10 (AGND), U6.15 (GND), U6.16 (AGND), U6.21 (PAD); also elsewhere on the board
MISO: U5.14 (SDO), U6.14 (SDO); also elsewhere on the board
MOSI: U5.11 (SDI), U6.11 (SDI); also elsewhere on the board
unnamed: R9.2, U5.1 (BIAS), U5.2 (REFIN+)
unnamed: R9.1, U5.3 (REFIN-), U5.4 (ISENSOR)
unnamed: C10.1, FB3.1, U5.20 (VDD)
unnamed: R11.2, U6.1 (BIAS), U6.2 (REFIN+)
unnamed: R11.1, U6.3 (REFIN-), U6.4 (ISENSOR)
unnamed: C13.1, FB4.1, U6.20 (VDD)
RTDIN3+: C11.1, U5.7 (RTDIN+); also elsewhere on the board
RTDIN3-: C11.2, U5.8 (RTDIN-); also elsewhere on the board
RTDIN4+: C14.1, U6.7 (RTDIN+); also elsewhere on the board
RTDIN4-: C14.2, U6.8 (RTDIN-); also elsewhere on the board
SCLK: U5.12 (SCLK), U6.12 (SCLK); also elsewhere on the board

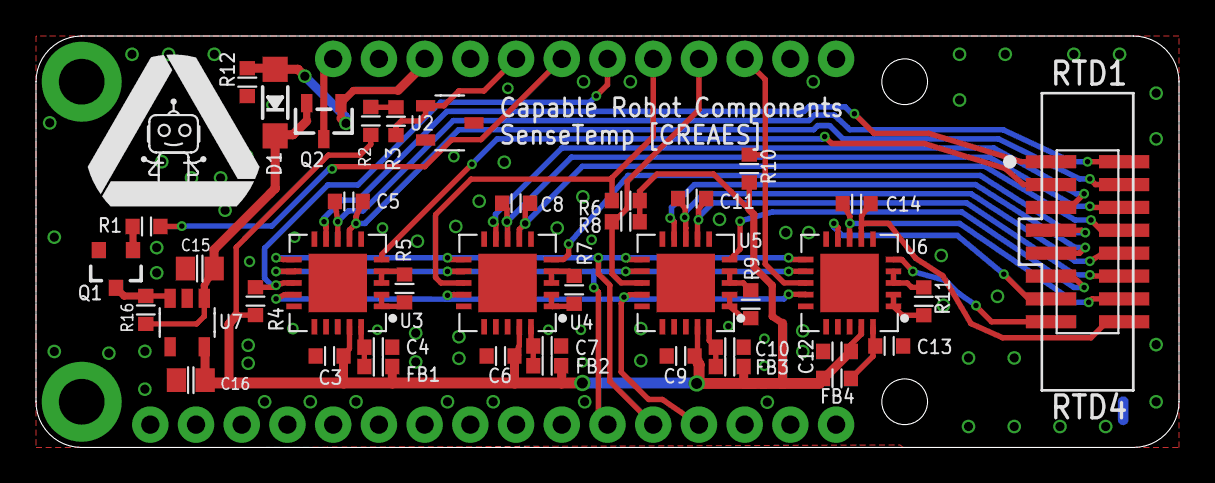
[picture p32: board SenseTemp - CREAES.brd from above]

Board: 2 copper layers, 63.5 x 22.9 mm, 44 parts (1 on the bottom side), 45 nets.

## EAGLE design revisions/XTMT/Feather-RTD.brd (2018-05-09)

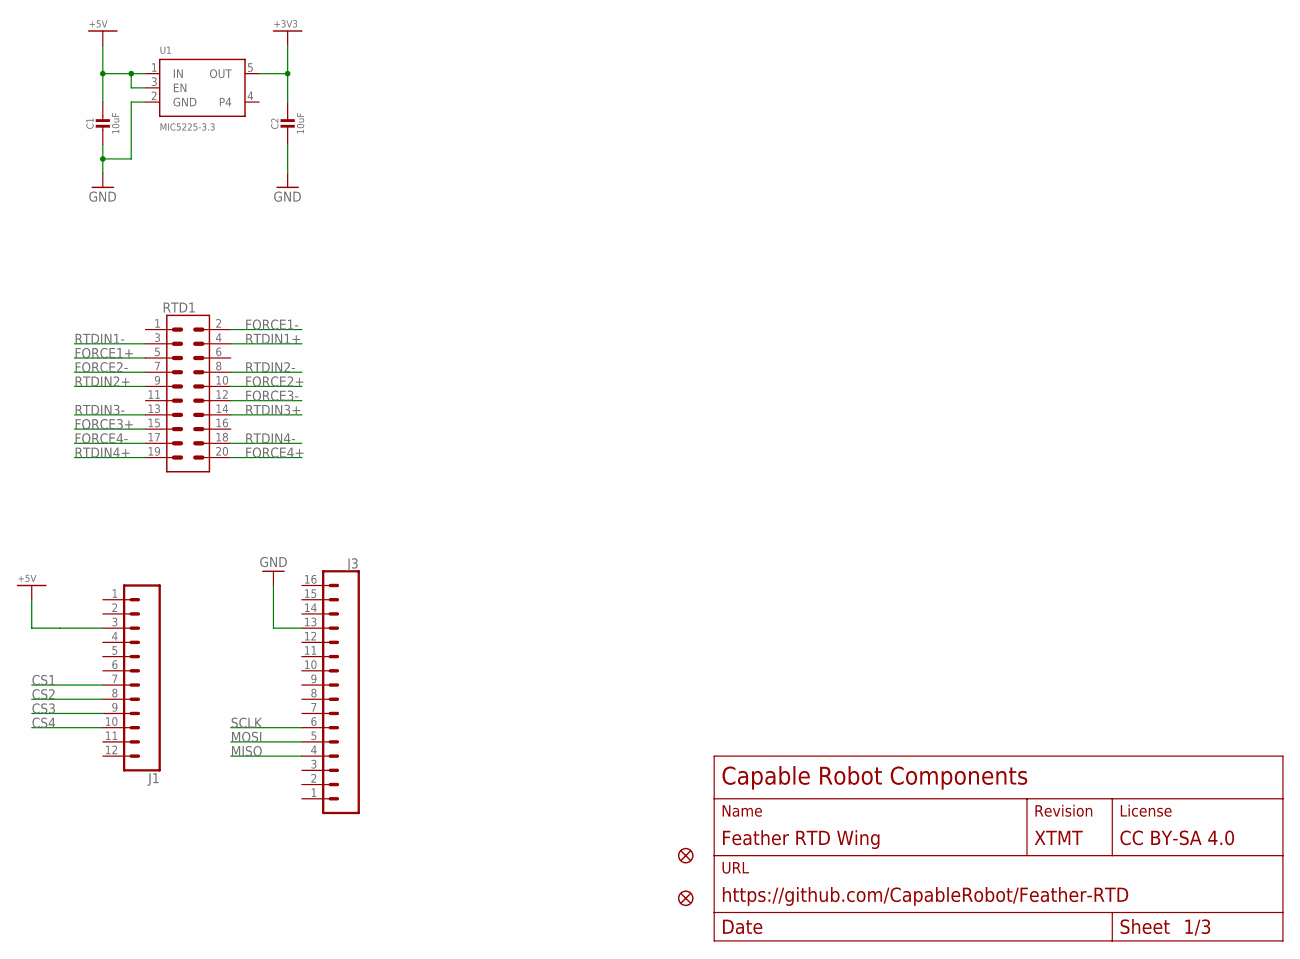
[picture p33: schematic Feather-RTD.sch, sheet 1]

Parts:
C1, C2: 10uF; 0805-NO
FID1, FID2: FIDUCIAL""; FIDUCIAL_1MM
J1: CONN_12NO_SILK; 1X12_NO_SILK
J3: CONN_161X16_NO_SILK; 1X16_NO_SILK
RTD1: CONN-20; CONN-2X10-050-SMT-ZT
U1: MIC5225-3.3; SOT23-5

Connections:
+3V3: C2.1, U1.5 (OUT); also elsewhere on the board
+5V: C1.1, J1.3, U1.1 (IN), U1.3 (EN)
CS1: J1.7; also elsewhere on the board
CS2: J1.8; also elsewhere on the board
CS3: J1.9; also elsewhere on the board
CS4: J1.10; also elsewhere on the board
FORCE1+: RTD1.5; also elsewhere on the board
FORCE1-: RTD1.2; also elsewhere on the board
FORCE2+: RTD1.10; also elsewhere on the board
FORCE2-: RTD1.7; also elsewhere on the board
FORCE3+: RTD1.15; also elsewhere on the board
FORCE3-: RTD1.12; also elsewhere on the board
FORCE4+: RTD1.20; also elsewhere on the board
FORCE4-: RTD1.17; also elsewhere on the board
GND: C1.2, C2.2, J3.13, U1.2 (GND); also elsewhere on the board
MISO: J3.4; also elsewhere on the board
MOSI: J3.5; also elsewhere on the board
RTDIN1+: RTD1.4; also elsewhere on the board
RTDIN1-: RTD1.3; also elsewhere on the board
RTDIN2+: RTD1.9; also elsewhere on the board
RTDIN2-: RTD1.8; also elsewhere on the board
RTDIN3+: RTD1.14; also elsewhere on the board
RTDIN3-: RTD1.13; also elsewhere on the board
RTDIN4+: RTD1.19; also elsewhere on the board
RTDIN4-: RTD1.18; also elsewhere on the board
SCLK: J3.6; also elsewhere on the board

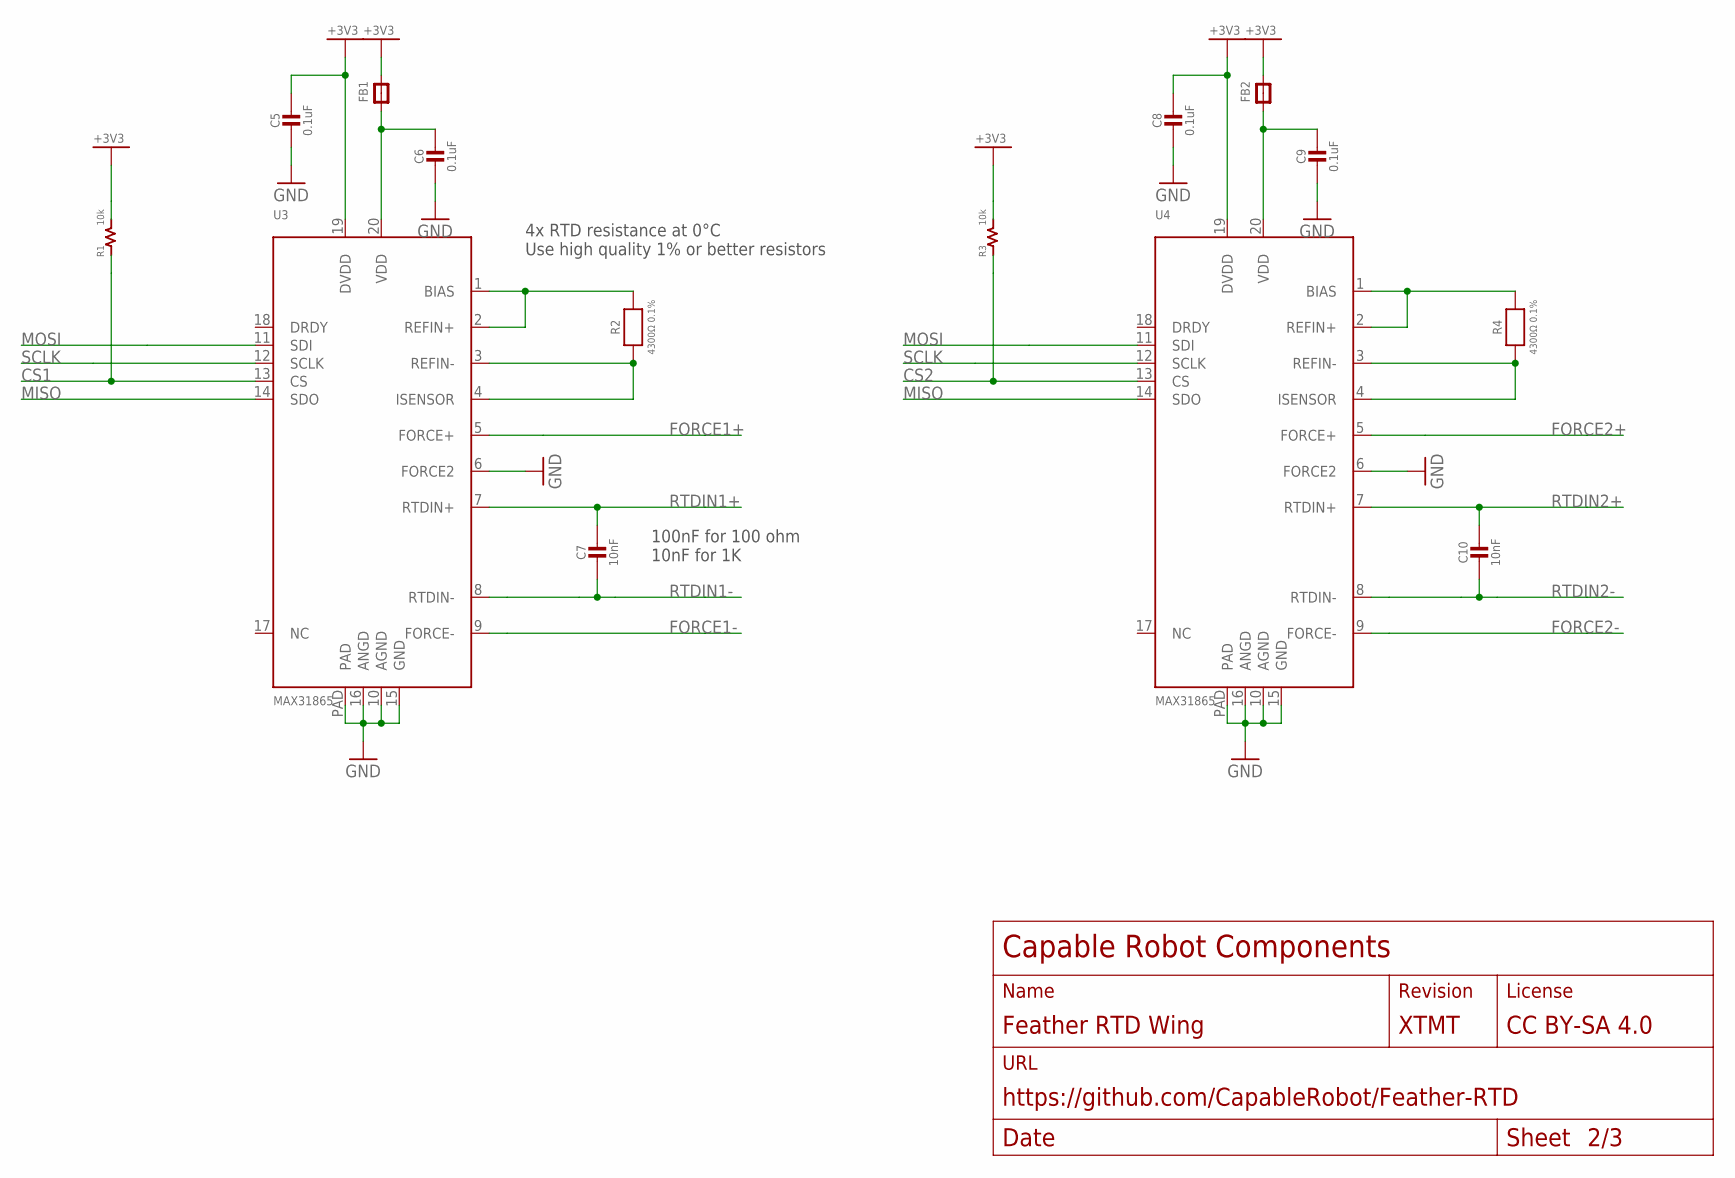
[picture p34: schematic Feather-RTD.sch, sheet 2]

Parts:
C5, C6, C8, C9: 0.1uF; 0805-NO
C7, C10: 10nF; 0805-NO
FB1, FB2: FERRITE-0805NO; 0805-NO
R1, R3: 10k; 0603
R2, R4: 4300Ω 0.1%; 0805-NO
U3, U4: MAX31865; QFN20_4MM_0.65MM

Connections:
+3V3: C5.1, C8.1, FB1.2, FB2.2, R1.2, R3.2, U3.19 (DVDD), U4.19 (DVDD); also elsewhere on the board
CS1: R1.1, U3.13 (CS); also elsewhere on the board
CS2: R3.1, U4.13 (CS); also elsewhere on the board
FORCE1+: U3.5 (FORCE+); also elsewhere on the board
FORCE1-: U3.9 (FORCE-); also elsewhere on the board
FORCE2+: U4.5 (FORCE+); also elsewhere on the board
FORCE2-: U4.9 (FORCE-); also elsewhere on the board
GND: C5.2, C6.2, C8.2, C9.2, U3.6 (FORCE2), U3.10 (AGND), U3.15 (GND), U3.16 (ANGD), U3.PAD, U4.6 (FORCE2), U4.10 (AGND), U4.15 (GND), U4.16 (ANGD), U4.PAD; also elsewhere on the board
MISO: U3.14 (SDO), U4.14 (SDO); also elsewhere on the board
MOSI: U3.11 (SDI), U4.11 (SDI); also elsewhere on the board
unnamed: R2.2, U3.1 (BIAS), U3.2 (REFIN+)
unnamed: R2.1, U3.3 (REFIN-), U3.4 (ISENSOR)
unnamed: C6.1, FB1.1, U3.20 (VDD)
unnamed: R4.2, U4.1 (BIAS), U4.2 (REFIN+)
unnamed: R4.1, U4.3 (REFIN-), U4.4 (ISENSOR)
unnamed: C9.1, FB2.1, U4.20 (VDD)
RTDIN1+: C7.1, U3.7 (RTDIN+); also elsewhere on the board
RTDIN1-: C7.2, U3.8 (RTDIN-); also elsewhere on the board
RTDIN2+: C10.1, U4.7 (RTDIN+); also elsewhere on the board
RTDIN2-: C10.2, U4.8 (RTDIN-); also elsewhere on the board
SCLK: U3.12 (SCLK), U4.12 (SCLK); also elsewhere on the board

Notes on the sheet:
4x RTD resistance at 0°C Use high quality 1% or better resistors
100nF for 100 ohm 10nF for 1K

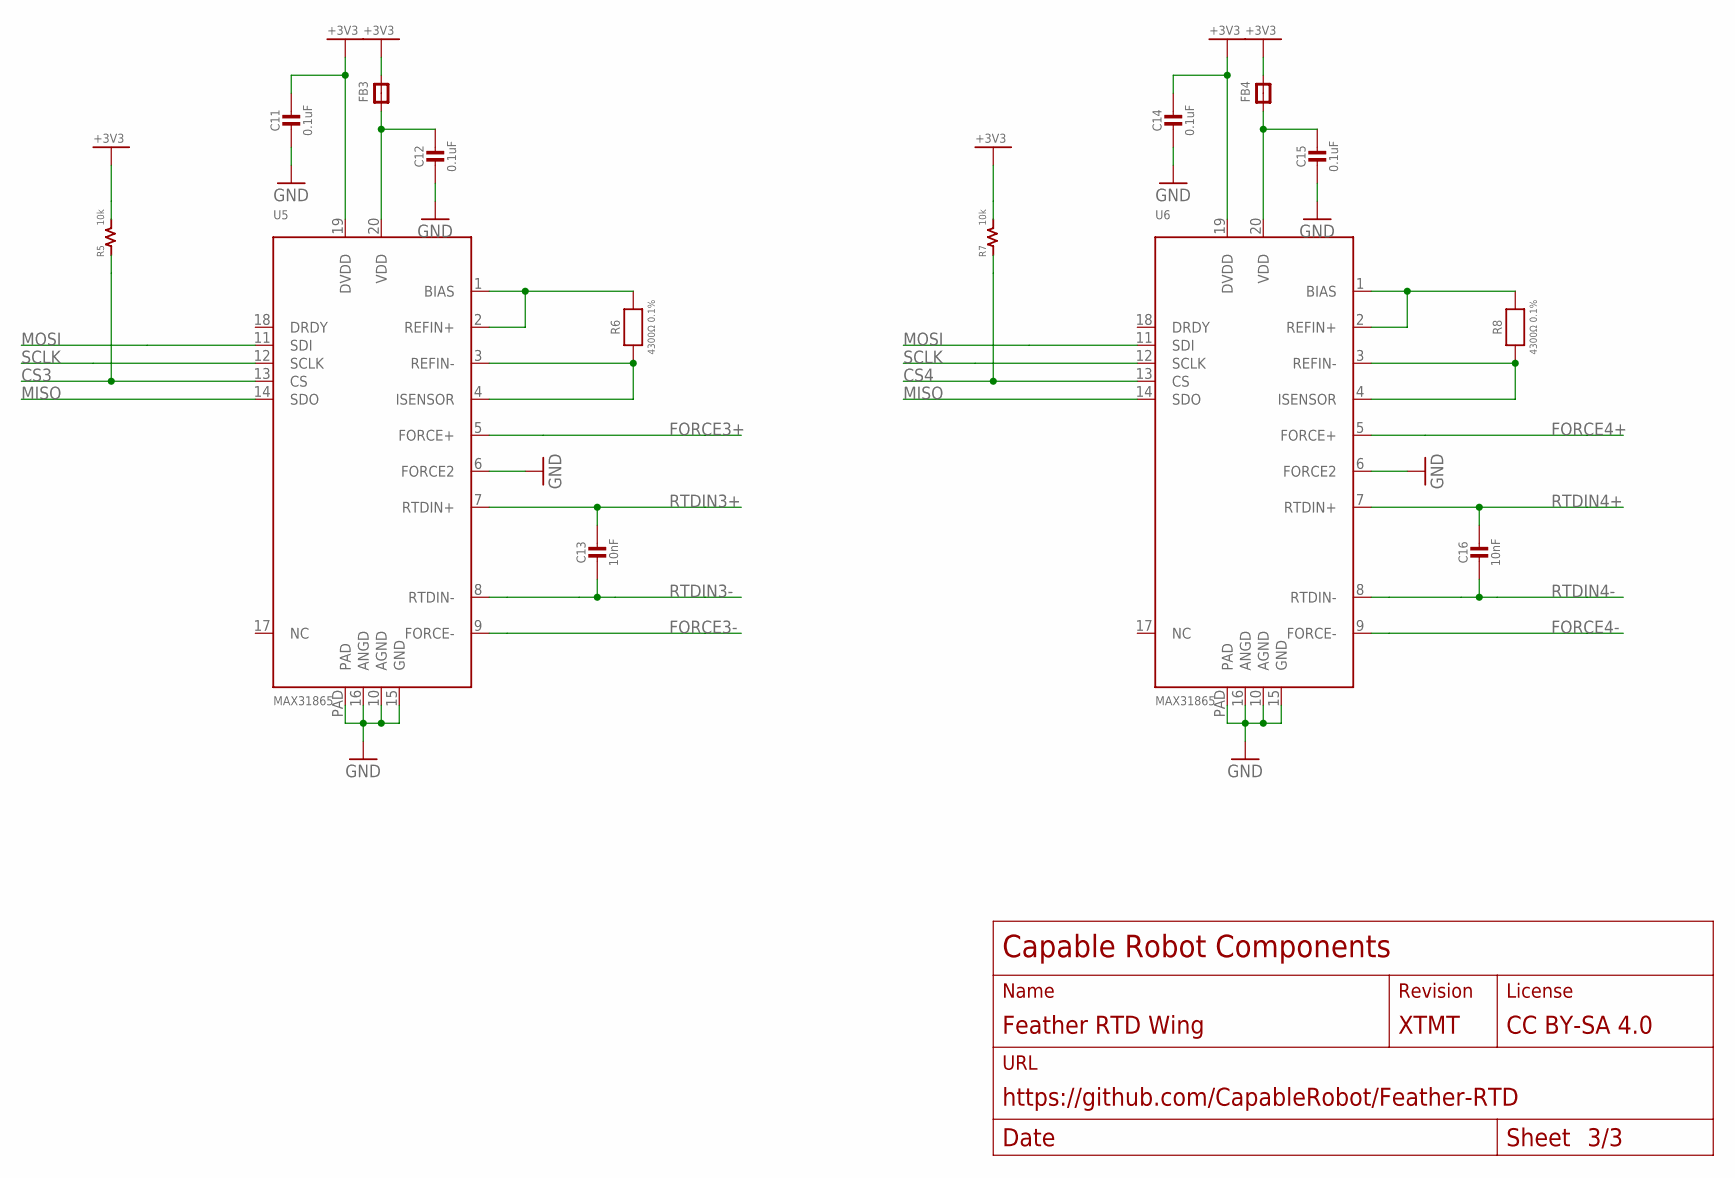
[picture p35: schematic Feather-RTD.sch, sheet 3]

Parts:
C11, C12, C14, C15: 0.1uF; 0805-NO
C13, C16: 10nF; 0805-NO
FB3, FB4: FERRITE-0805NO; 0805-NO
R5, R7: 10k; 0603
R6, R8: 4300Ω 0.1%; 0805-NO
U5, U6: MAX31865; QFN20_4MM_0.65MM

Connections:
+3V3: C11.1, C14.1, FB3.2, FB4.2, R5.2, R7.2, U5.19 (DVDD), U6.19 (DVDD); also elsewhere on the board
CS3: R5.1, U5.13 (CS); also elsewhere on the board
CS4: R7.1, U6.13 (CS); also elsewhere on the board
FORCE3+: U5.5 (FORCE+); also elsewhere on the board
FORCE3-: U5.9 (FORCE-); also elsewhere on the board
FORCE4+: U6.5 (FORCE+); also elsewhere on the board
FORCE4-: U6.9 (FORCE-); also elsewhere on the board
GND: C11.2, C12.2, C14.2, C15.2, U5.6 (FORCE2), U5.10 (AGND), U5.15 (GND), U5.16 (ANGD), U5.PAD, U6.6 (FORCE2), U6.10 (AGND), U6.15 (GND), U6.16 (ANGD), U6.PAD; also elsewhere on the board
MISO: U5.14 (SDO), U6.14 (SDO); also elsewhere on the board
MOSI: U5.11 (SDI), U6.11 (SDI); also elsewhere on the board
unnamed: R6.2, U5.1 (BIAS), U5.2 (REFIN+)
unnamed: R6.1, U5.3 (REFIN-), U5.4 (ISENSOR)
unnamed: C12.1, FB3.1, U5.20 (VDD)
unnamed: R8.2, U6.1 (BIAS), U6.2 (REFIN+)
unnamed: R8.1, U6.3 (REFIN-), U6.4 (ISENSOR)
unnamed: C15.1, FB4.1, U6.20 (VDD)
RTDIN3+: C13.1, U5.7 (RTDIN+); also elsewhere on the board
RTDIN3-: C13.2, U5.8 (RTDIN-); also elsewhere on the board
RTDIN4+: C16.1, U6.7 (RTDIN+); also elsewhere on the board
RTDIN4-: C16.2, U6.8 (RTDIN-); also elsewhere on the board
SCLK: U5.12 (SCLK), U6.12 (SCLK); also elsewhere on the board

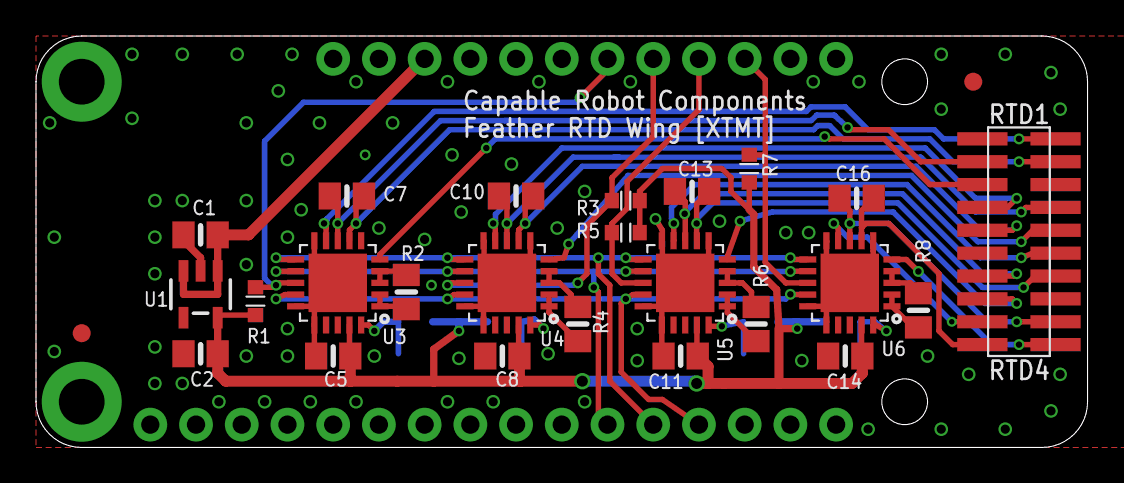
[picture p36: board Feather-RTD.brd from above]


Board: 2 copper layers, 58.4 x 22.9 mm, 36 parts (8 on the bottom side), 38 nets.

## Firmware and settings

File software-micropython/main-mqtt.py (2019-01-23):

## MicroPython Imports
import time
import machine
import network
import gc
import ujson as json
import mqtt

## Local Imports
import adafruit_max31865 as max31865

def check_wifi(nic):
    if 'wifi-station' not in settings:
        return

    if nic.isconnected():
        return

    nic.connect(settings['wifi-station']['name'], settings['wifi-station']['pass'])

    while not nic.isconnected():
        time.sleep(0.2)

def poll_sensors(extra_info=False):
    samples = []

    for idx, sensor in sensors:
        value = sensor.temperature*settings['device']['scale']

        if settings['device']['to_int']:
            value = int(value)

        samples.append([sensor_info[idx-1]['name'],value])

    return samples

def format_data(data):
    return "\n".join(s[0]+","+str(s[1]) for s in data)    

settings = json.load(open("settings-mqtt.json", 'r'))

RTD_NOMINAL   = 1000.0  ## Resistance of RTD at 0C
RTD_REFERENCE = 4300.0  ## Value of reference resistor on PCB

## Create Software SPI controller.  MAX31865 requires polarity of 0 and phase of 1.
## Currently, the micropython on the ESP32 does not support hardware SPI
sck  = machine.Pin( 5, machine.Pin.OUT)
mosi = machine.Pin(18, machine.Pin.IN)
miso = machine.Pin(19, machine.Pin.OUT)
spi  = machine.SPI(baudrate=50000, sck=sck, mosi=mosi, miso=miso, polarity=0, phase=1)

## Create SPI Chip Select pins
cs1  = machine.Pin(33, machine.Pin.OUT, value=1)
cs2  = machine.Pin(15, machine.Pin.OUT, value=1)
cs3  = machine.Pin(32, machine.Pin.OUT, value=1)
cs4  = machine.Pin(14, machine.Pin.OUT, value=1)
css  = [cs1, cs2, cs3, cs4]

sensors     = []
sensor_info = []
idx         = 0

## Create array of active RTD sensors and information about them
for name in settings['device']['sensors']:
    idx += 1

    if name.upper() == "DISABLE":
        continue

    sensors.append([
        idx,
        max31865.MAX31865(
            spi, css[idx-1],
            wires        = 4,
            rtd_nominal  = RTD_NOMINAL,
            ref_resistor = RTD_REFERENCE)
    ])

    sensor_info.append({
        "id"       : idx,
        "scale"    : settings['device']['scale'],
        "type"     : "temperature",
        "sensor"   : "RTD1000 -> MAX31865",
        "name"     : name
    })

print("WIFI : Connecting ....")

## Setup WIFI Networking as a client
if 'wifi-station' in settings:
    nic = network.WLAN(network.STA_IF)
    nic.active(True)
    check_wifi(nic)

print("WIFI : Connected ")

## Clean out allocated memory so far
gc.collect()
gc.threshold(gc.mem_free() // 4 + gc.mem_alloc())

## Create MQTT Connection
c = mqtt.MQTTClient(
    client_id = settings['device']['name'], 
    server    = settings['mqtt']['server'], 
    user      = settings['mqtt']['user'],
    password  = settings['mqtt']['key'],

    ssl=False
)

print("MQTT Client : Created")

c.connect()
print("MQTT Client : Connected")

# Publish temperatures to Adafruit IO using MQTT
#
# Format of feed name:  
#   "ADAFRUIT_USERNAME/groups/ADAFRUIT_IO_GROUPNAME"
mqtt_feedname = bytes('{:s}/groups/{:s}/csv'.format(settings['mqtt']['user'], settings['mqtt']['feed']), 'utf-8')

while True:
    check_wifi(nic)

    # Multiple topics can be published with one message if the CSV form is used:
    #   SENSORNAME1,VALUE1
    #   SENSORNAME1,VALUE2
    #
    # `poll_sensors` returns [[name1,value1],[name2,value2],...] formatted data
    # `format_data` transforms that data into this CSV string form
    #
    # Measurements will appear as
    #   USERNAME/feeds/FEEDNAME.SENSORNAME1
    #   USERNAME/feeds/FEEDNAME.SENSORNAME2
    #   USERNAME/feeds/FEEDNAME.SENSORNAME3
    #   USERNAME/feeds/FEEDNAME.SENSORNAME4
    #
    # where the following are specified in the settings JSON file:
    #   FEEDNAME is settings['mqtt']['feed']
    #   SENSORNAME_ is the settings['device']['sensors'] array
    c.publish(mqtt_feedname, format_data(poll_sensors()))

    time.sleep(settings['mqtt']['sleep'])
    gc.collect()

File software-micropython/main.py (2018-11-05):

## MicroPython Imports
import time
import machine
import network
import gc
import ujson as json
from    _thread     import start_new_thread

## Local Imports
import adafruit_max31865 as max31865

def check_wifi(nic):
    if 'wifi-station' not in settings:
        return

    if nic.isconnected():
        return

    nic.connect(settings['wifi-station']['name'], settings['wifi-station']['pass'])

    while not nic.isconnected():
        time.sleep(0.2)

def wait_ap(ap):
    if ap.active() and ap.isconnected():
        print("AP Already Started")
        return

    while not ap.active() and not ap.isconnected():
        print('***')
        time.sleep(0.2)

    print("AP Now Started")

def mean(data):
    return sum(data)/float(len(data))

def _ss(data):
    c = mean(data)
    ss = sum((x-c)**2 for x in data)
    return ss

def stddev(data, ddof=0):
    ss = _ss(data)
    pvar = ss/(len(data)-ddof)
    return pvar**0.5

def poll_sensors(extra_info=False):
    meta    = []
    samples = []

    for idx, sensor in sensors:
        value = sensor.temperature*settings['device']['scale']

        if settings['device']['to_int']:
            value = int(value)

        data = {'id':idx, 'value':value}

        if extra_info:
            data['name'] = sensor_info[idx-1]['name']

        meta.append(data)
        samples.append(value)

    meta.append({'id':'agg','mean':mean(samples),'stddev':stddev(samples)})
    return meta


def mqtt_loop():
    ## Create MQTT Connection
    c = mqtt.MQTTClient(settings['device']['name'], settings['mqtt']['ip'], 1883)
    c.connect()
    c.publish(settings['device']['name'], json.dumps(sensor_info))

    while True:
        check_wifi(nic)
        c.publish(settings['device']['name'], json.dumps(poll_sensors()))
        time.sleep(settings['mqtt']['sleep'])


settings = json.load(open("settings.json", 'r'))

RTD_NOMINAL   = 1000.0  ## Resistance of RTD at 0C
RTD_REFERENCE = 4300.0  ## Value of reference resistor on PCB
HTTP_HEADERS  = {"Access-Control-Allow-Origin": "*"}

## Create Software SPI controller.  MAX31865 requires polarity of 0 and phase of 1.
## Currently, the micropython on the ESP32 does not support hardware SPI
sck  = machine.Pin( 5, machine.Pin.OUT)
mosi = machine.Pin(18, machine.Pin.IN)
miso = machine.Pin(19, machine.Pin.OUT)
spi  = machine.SPI(baudrate=50000, sck=sck, mosi=mosi, miso=miso, polarity=0, phase=1)

## Create SPI Chip Select pins
cs1  = machine.Pin(33, machine.Pin.OUT, value=1)
cs2  = machine.Pin(15, machine.Pin.OUT, value=1)
cs3  = machine.Pin(32, machine.Pin.OUT, value=1)
cs4  = machine.Pin(14, machine.Pin.OUT, value=1)
css  = [cs1, cs2, cs3, cs4]

sensors     = []
sensor_info = []
idx         = 0

## Create array of active RTD sensors and information about them
for name in settings['device']['sensors']:
    idx += 1

    if name.upper() == "DISABLE":
        continue

    sensors.append([
        idx,
        max31865.MAX31865(
            spi, css[idx-1],
            wires        = 4,
            rtd_nominal  = RTD_NOMINAL,
            ref_resistor = RTD_REFERENCE)
    ])

    sensor_info.append({
        "id"       : idx,
        "scale"    : settings['device']['scale'],
        "type"     : "temperature",
        "sensor"   : "RTD1000 -> MAX31865",
        "name"     : name
    })



## Setup WIFI Networking as a client
if 'wifi-station' in settings:
    nic = network.WLAN(network.STA_IF)
    nic.active(True)
    check_wifi(nic)

## Setup WIFI Networking as an access point
if 'wifi-ap' in settings:
    ap = network.WLAN(network.AP_IF)
    ap.active(True)
    ap.config(essid=settings['wifi-ap']['name'])
    wait_ap(ap)

## Clean out allocated memory so far
gc.collect()
gc.threshold(gc.mem_free() // 4 + gc.mem_alloc())

## Become a MQTT client, if configured so
if 'mqtt' in settings:
    import mqtt
    # start_new_thread(mqtt_thread, ())
    mqtt_loop()




def _acceptWebSocketCallback(webSocket, httpClient) :
    print("WS ACCEPT")
    webSocket.RecvTextCallback   = _recvTextCallback
    webSocket.RecvBinaryCallback = _recvBinaryCallback
    webSocket.ClosedCallback     = _closedCallback

def _recvTextCallback(webSocket, msg):
    print("WS RECV TEXT : %s" % msg)
    webSocket.SendText("Reply for %s" % msg)

def _recvBinaryCallback(webSocket, data):
    print("WS RECV DATA : %s" % data)

def _closedCallback(webSocket):
    print("WS CLOSED")

def _handle_datajson_get(httpClient, httpResponse, routeArgs=None):

    data = poll_sensors(extra_info=True)

    ## For convenience, add in:
    ##  each sensor's name (from the settings file)
    ##  and sensor global configuration (scale & int conversion)
    # for entry in data:
    #     if entry['id'] == 'agg':
    #         entry['scale']  = settings['device']['scale']
    #         entry['to_int'] = settings['device']['to_int']
    #     else:
    #         entry['name'] = sensor_info[entry['id']-1]['name']

    httpResponse.WriteResponseJSONOk(obj=data, headers=HTTP_HEADERS)

if 'http' in settings:
    from microWebSrv import MicroWebSrv

    handlers = [
      ( "/data.json", "GET", _handle_datajson_get ),
    ]

    mws = MicroWebSrv(routeHandlers=handlers, webPath='/www')
    mws.MaxWebSocketRecvLen     = 64     # Default is set to 1024
    mws.WebSocketThreaded       = False  # WebSockets without new threads
    mws.AcceptWebSocketCallback = _acceptWebSocketCallback

    ## Does not work, silently fails
    ## Might be due to attempting to start 10 threads
    # mws.Start()

    ## Works, but blocks the REPL
    mws.Start(threaded = False)

    ## Sometimes works
    # start_new_thread(mws._serverProcess, ())

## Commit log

2018-04-02 Initial commit of software for ESP32 running MicroPython
2018-05-09 Added XTMT hardware design files
    [Feather-RTD.brd, Feather-RTD.sch]
2018-05-09 Move atributed from page 1 title block to global
    [Feather-RTD.brd, Feather-RTD.sch]
2018-08-28 Adding X9EG version, out for fab
    [Feather RTD - X9EG.brd, Feather RTD - X9EG.sch]
2018-09-21 Fix encoding issue. Change location of some keys in JSON settings. Move to threading model
    [main.py]
2018-10-18 Adding CREAES version - adds user LED and all components on top side
    [SenseTemp - CREAES.brd, SenseTemp - CREAES.sch]
2018-10-18 Adding BOM and json version of X9EG version
    [Bill of Materials.csv, Feather RTD - X9EG.brd]
2018-10-18 Fix location of REV label
    [SenseTemp - CREAES.sch]
2018-10-23 Fix issus where sensor data and metadata was publishes on different MQTT topics. Changed to not be a thread.
    [main.py]
2018-11-08 Adding circuit python code for SenseTemp on the HalloWing
2018-11-08 Added readme to hardware folder. Added note about Li-Ion power source.
2018-11-08 Added README with example circuitpython code
2018-12-04 Added Feather M0/M4 which prints temperature data to the serial console.
2018-12-04 Change color of on-board LED based on RTD1
2018-12-20 Adding example code for displaying temperature on a OLED screen
2019-05-10 Adding auto-calibration script
2019-08-13 Change silk screen around RTD connector
    [Bill of Materials.csv, SenseTemp - CREAES.brd, SenseTemp - CREAES.sch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]
2020-08-28 Adding adapter PCBs to allow connection to 2 wire and 3 wire RTDs
    [Adapter - Cabled 2 wire [CRXB4M].brd, Adapter - Cabled 2 wire [CRXB4M].sch, Adapter - Stacking 2 wire [CRY8EI].brd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]

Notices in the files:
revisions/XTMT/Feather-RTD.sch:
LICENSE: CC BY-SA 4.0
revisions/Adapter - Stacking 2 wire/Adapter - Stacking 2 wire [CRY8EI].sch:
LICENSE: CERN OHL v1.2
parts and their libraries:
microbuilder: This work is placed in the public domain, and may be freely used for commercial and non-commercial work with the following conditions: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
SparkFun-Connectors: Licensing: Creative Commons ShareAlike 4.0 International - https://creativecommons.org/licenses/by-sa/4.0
